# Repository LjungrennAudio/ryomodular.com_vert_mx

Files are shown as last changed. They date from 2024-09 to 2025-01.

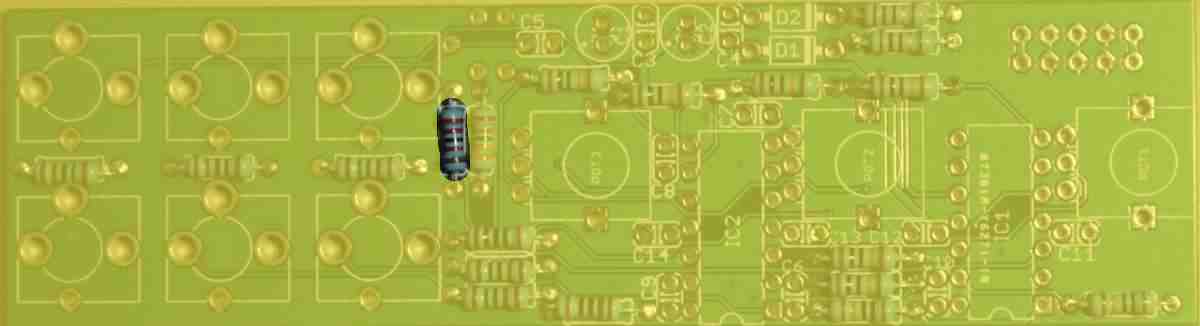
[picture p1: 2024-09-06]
docs/vert_mx/build pics/08 22k.jpg

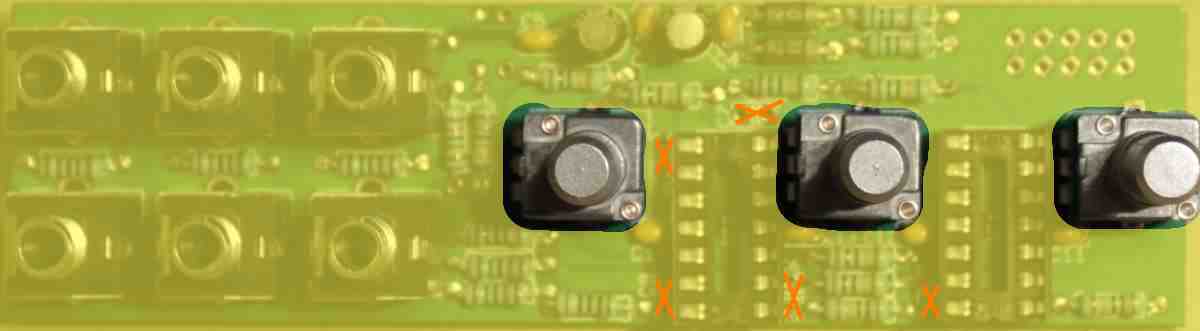
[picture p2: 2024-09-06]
docs/vert_mx/build pics/15 pots.jpg

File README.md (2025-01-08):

# ryomodular.com_vert_mx
 yet another new ryomodule - thi time the lon overdue vertmix mixer

2408302315

this is the repo for the ryodular.com vert_mx urorack format modular synth mixer module.

its been around as a prototypefor near 13 years and even visible on mod grid etc. yet never released so i guess it's about time really...

it's not much exciting am afraid - a 3 channel mixer with attenu version on each channel as well asbreakout signal option to allow just utility use without being used as a mixer.

it will  be available in ht new white panel/gold markings n pink knobs plus green leds along with the traditional ryo colourscheme too.
it should  be a pretty low price basic beginner DIY build friendly kinda module as oer ryo's traditional so far iutput so may not catch as much attention as the other new modules in the lineup but i feel c9mpelled to bring this cha[pter to closure at whatever cost the way things seem to be going. : D

if anyone cn come up with real exciting patch progaramming uses or unusuial thoughts for patch examples please tell me cos am not super inspired by thios one tbh - it's absolutely an essential you cnt do without in a system but it's not exactly the kimda thing you shout about - it just sits queitly in the corner doing it's job and eing an unsung hero of the modular ecosystem.

this will be cheap, unexciting and solid. it needs to e there as oart of the lineup but its not a weird quirky one or some kind of flagship - it just is.

202501080338 addendum

this is p much exactly the same story as the repos for the other modules of the set 'vert_mx, dp_switch, adda. brit_eq5', - i.e. it's not finished until it's finished and i aint attempting to bring order to chaos until it's all over so for now this aint gonna be sereing alotta change except for even more files being added. sorro.

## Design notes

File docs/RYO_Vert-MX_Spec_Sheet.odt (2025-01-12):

LjunggrenAudio RYOModular.com VERT_MX

A Three Channel Bipolar Attenuverting Mixer.

Dimensions

Height: 3U (128.5mm)

Width: 8HP (40.30mm)

Depth: ??mm (with power cable attached)

Weight: ???g (approx w/cable)

Current consumption

+12V rail 30mA

-12V rail 8mA

+5V rail no +5V supply required

Basic specifications

total frequency controllable range dc to 50kHz

max input/output audio signal 20Vpp

CV input range -10V to +10V

Max gain n/a

Nominal impedances

Audio signal input: ???ohm
Audio Signal output: ???ohm

CV input: ??kohm

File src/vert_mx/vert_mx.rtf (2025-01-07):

Vertmix

Download assembly manual here. (https://web.archive.org/web/20200128094051/http://ljunggrenaudio.com/vertmix.pdf)

Vertmix is out of production, new version coming but we don't know when.
It will have surface mounted resistors and ceramic capacitors in 0805 size. The rest of the components will be thru hole. Preliminary PCB illustration of version 1.5. (https://web.archive.org/web/20200128094051/http://ljunggrenaudio.com/products/VERTMIX/vertmixPCB1.5.gif)

* Regarding our PCB/panel only offerings, please note that these are mainly offered due to popular demand from the experienced DIY community. Hence we are counting on that you know what you are doing and how to source parts. If you feel the least bit uncertain, please consider going for the kit.

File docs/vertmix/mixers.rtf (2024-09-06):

Mixers

Ampmix

Download assembly manual here. (1MB) (https://web.archive.org/web/20200128094051/http://ljunggrenaudio.com/ampmix.pdf)
(https://web.archive.org/web/20200128094051/http://ljunggrenaudio.com/optodist.pdf)
An easy to build 4-channel amplifying mixer/attenuator with 2.0x gain (6dB) and 5.0V offset on each channel in an 8hp module. No calibration required.

Ampmix was designed as a handy CV mixer and processor with good precision, high input impedance and buffered outputs. It could be upgraded for even better precision as described in the assembly manual.

It will also work great with audio, even with full gain giving some distortion possibilities or gaining external gear.

It works as a 4 channel mixer,
1 attenuator + 3 channel mixer,
2 attenuators + 2 channel mixer
or 4 attenuators.
With up to 2.0x gain (6dB) on each channel.

If you chain channels you can get greater gain. You can chain any combination of channels it doesn't have to be in the described order.
Patch signal to IN1, OUT1 -> IN2 and OUT2 have 4x gain (12dB) total.
Continue with OUT2 -> IN3 and OUT3 have 8x gain (18dB) total.
Continue with OUT3 -> IN4 and OUT4 have 16x gain (24dB) total.

An offset voltage is generated then normaled to the inputs of the 4 channels, giving them a maximum of 5V out each with knobs turned full clockwise (2.0x gain). Please note that these offsets will affect the mixing if the channel hasn't been patched on its input or output, so turning all unused channels fully counter-clockwise/left (off) is advisable for a clean mix.

The Ampmix Kit is a novice-friendly project, it is a low part count, single-PCB build that only requires the most basic experience in PCB soldering and module assembly. Kits comes supplied with PCB, front panel (PCB material), component kit, knobs, power cable and mounting screws. Solder and tools are not supplied.

Download assembly manual here. (1MB) (https://web.archive.org/web/20200128094051/http://ljunggrenaudio.com/ampmix.pdf)
Download schematics here. (https://web.archive.org/web/20200128094051/http://ljunggrenaudio.com/products/AMPMIX/ampmix%20schematics%201.3.gif)

Basic specifications
Width: 8hp
Depth with power cable attached: Less than 35 mm.
Power: +/- 22 mA

Vertmix

Download assembly manual here. (https://web.archive.org/web/20200128094051/http://ljunggrenaudio.com/vertmix.pdf)

Vertmix is out of production, new version coming but we don't know when.
It will have surface mounted resistors and ceramic capacitors in 0805 size. The rest of the components will be thru hole. Preliminary PCB illustration of version 1.5. (https://web.archive.org/web/20200128094051/http://ljunggrenaudio.com/products/VERTMIX/vertmixPCB1.5.gif)

* Regarding our PCB/panel only offerings, please note that these are mainly offered due to popular demand from the experienced DIY community. Hence we are counting on that you know what you are doing and how to source parts. If you feel the least bit uncertain, please consider going for the kit.

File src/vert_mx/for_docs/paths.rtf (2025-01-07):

Switches

PATHS - A Cycling Sequential Switch

A 4:4 cycling sequential switch, featuring simultaneous forward/reverse stepping, hold, reset, and an additional voltage controlled mode based on the same design as our VC Sequencer. Also on board are push buttons for each function enabling you to play and perform the switching with a more human input.

This sequential switch will do all your standard 1>2, 1>3, 1>4 or the other way around with great real-time as well as external voltage controllability.

But its when you start playing around with multiple sources and destinations that things start getting fun and weird! You could for instance shuffle around four different trigger patterns to trigger four different percussive generators for interesting variations, or why not 4 oscillators shuffling between 4 different destinations, panned and processed in various ways?

Whatever your sequential switch application might be, we're confident the Paths is up to the task!

Just like the VC Sequencer it is clockable by very high clock rates (100 kHz tested) and CVable with full audio range. All for your experimental waveshaping duties.

Clock Mode
When clocking with FWD clock input or button the sequence will advance one step forward. When clocking with REV clock input or button the sequence will advance one step in reverse.

If a clock comes in exactly at the same time on both inputs the forward will have priority over the reverse.

CV Mode
In CV mode there is two CV inputs. The one that shares the reverse clock input is full wave rectified and the one that shares the forward clock input is half wave rectified. It uses an active rectifier without voltage drop or a dead zone around 0V.

The half wave rectified (FWD) with one bump on the rectifier symbol, will clip any signal below 0V and above 5V. The difference to the full wave rectified input (REV) with two bumps on the rectifier symbol, is that it will turn any negative volt into positive as well. So -1V is the same as +1V and -5V is the same as +5V etc.

The CV inputs are mixed together so they can be used at the same time.

The steps toggle switch and the red buttons are inactive in CV mode.
To limit the number of steps in CV mode you can use an attenuator to attenuate the CV down to only reach 2 or 3 steps.

Four separate switches
It's essentially four separate switches that is commonly controlled and shares ins and outs.
When I/O1 is connected to O/I1, I/O2 is connected to O/I2 and so on.
When I/O1 is connected to O/I2, I/O2 is connected to O/I3 and so on, and I/O4 is connected to O/I1.
When I/O1 is connected to O/I3, I/O2 is connected to O/I4 and I/O3 is connected to O/I1 and so on.
All the routings can be seen in the picture linked here, each module represent one of the four steps as the LEDs next to the jacks indicate. (https://web.archive.org/web/20200129120501/http://ljunggrenaudio.com/products/PATHS/pathsrouting.png)

2/4/3 Steps and reverse direction.
The toggle switch that controls number of steps works a little pequliar due to the CMOS CD4516 counter IC. Reset always takes it back to step 1/first LED lit. We could then choose to always let it reset on step 3 and 4 respectively for 2 and 3 steps.

But when run in reverse it would mean that with the toggle switch on 2 steps it would go 2 steps before it hits step 3 and resets. All good so far but when 3 steps were selected it would just stay on step 1 when clocked in reverse as step 4 would be next and that would reset it. So we choose to let it reset on step 2 when you run it in reverse so it goes 1 -> 4 -> 3 -> 1.

This opens up the possibility to clock forward and reverse with different triggers or button presses and therefore make it go in controlled irregular patterns. 1 -> FWD -> 2 -> FWD -> 3 -> REV -> 1 -> REV -> 4 -> REV -> 3-> FWD -> 1 as an example. Add a little random trigs or button presses and it will be less controlled.

Two parallel 1:2 switches
You could also patch it like two commonly controlled parallel 1:2 switches if you only run it in one direction. Easiest is forward direction: I/O1 : O/I1 & O/I2 respectively I/O3 : O/I3 & O/I4

Kits and price
Kits comes supplied with PCBs, front panel (PCB material), component kit, power cable and mounting screws. Solder and tools are not supplied.

Download assembly instructions and BOM here (2.7MB). (https://web.archive.org/web/20200129120501/http://ljunggrenaudio.com/paths.pdf)
Download schematics here. (https://web.archive.org/web/20200129120501/http://ljunggrenaudio.com/products/PATHS/PATHS%201.1%20schematic.gif)

Basic specifications
Width: 8 hp
Depth: 46 mm.
Power: +12V 30 mA / -12V 8 mA

* Regarding our PCB/panel only offerings, please note that these are mainly offered due to popular demand from the experienced DIY community. Hence we are counting on that you know what you are doing and how to source parts. If you feel the least bit uncertain, please consider going for the kit.

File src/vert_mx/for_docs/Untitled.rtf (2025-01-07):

Anatomy of a module page

QuickStart

What’s in manual - each section as a bullet

Links to dls

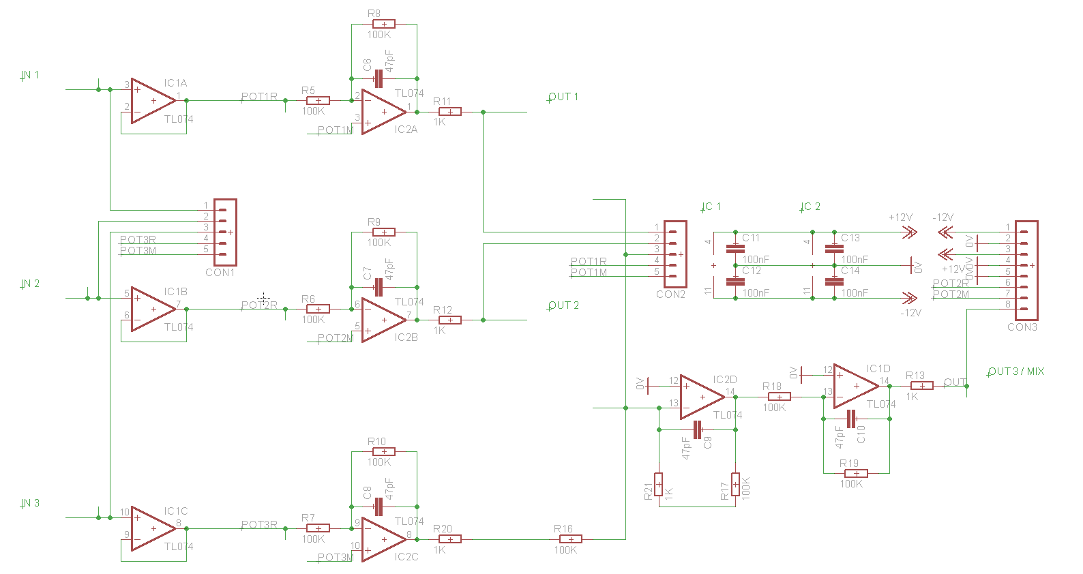
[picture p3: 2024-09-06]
docs/vertmix/downloads/vertmix pcb 2 schematic.png

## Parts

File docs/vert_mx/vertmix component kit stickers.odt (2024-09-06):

R16, R17 Resistor 2 pcs Value: 2K Vertmix 1.0 www.ljunggrenaudio.com | | R5, R6, R7, R8, R9, R10, R18, R19 Resistor 8 pcs Value: 100K Vertmix 1.0 www.ljunggrenaudio.com | | R11, R12, R13, R14, R15 Resistor 5 pcs Value: 1K Vertmix 1.0 www.ljunggrenaudio.com
R1, R2 Resistor 2 pcs Value: 10R Vertmix 1.0 www.ljunggrenaudio.com | | R4 Resistor 1 pcs Value: 22K Vertmix 1.0 www.ljunggrenaudio.com | | R3 Resistor 1 pcs Value: 33K Vertmix 1.0 www.ljunggrenaudio.com
TRIM1 Trimmer 1 pcs Value: 20K Vertmix 1.0 www.ljunggrenaudio.com | | C1, C2 Electrolytic 2 pcs Value: 10µF Vertmix 1.0 www.ljunggrenaudio.com | | C3, C4, C5, C11, C12, C13, C14 Capacitor 7 pcs Value: 100nF X7R ceramic Vertmix 1.0 www.ljunggrenaudio.com
POWER CABLE | | J1, J2, J3, J4, J5, J6 3.5mm jack 6 pcs PJ301BM washer 6 pcs nut 6 pcs Vertmix 1.0 www.ljunggrenaudio.com | | POT1, POT2, POT3 Rotary potentiometer 3 pcs Value: 100K Linear taper Vertmix 1.0 www.ljunggrenaudio.com
POWER Power header 1 pcs 10 pin boxed keyed header Vertmix 1.0 www.ljunggrenaudio.com | | Knobs Small fluted skirtless, cream 3 pcs Vertmix 1.0 www.ljunggrenaudio.com | | Mounting screws M3x6, Pozi, Black 2 pcs Vertmix 1.0 www.ljunggrenaudio.com
PCB 1 pcs Vertmix 1.0 www.ljunggrenaudio.com | | Faceplate 6hp 2mm, PCB (FR4) material 1 pcs black Vertmix 1.0 www.ljunggrenaudio.com | | Roll Your Own KIT Vertmix 1.0 Assembly manual as PDF can be found here: http://ljunggrenaudio.com/vertmix.pdf www.ljunggrenaudio.com

IC1, IC2 14 pin DIP socket 2 pcs TL084 2 pcs Vertmix 1.0 www.ljunggrenaudio.com | | IC1, IC2 14 pin DIP socket 2 pcs TL074 2 pcs Vertmix 1.0 www.ljunggrenaudio.com | | ← ONE
D1, D2 Diode 2 pcs SB130 Schottky Vertmix 1.0 www.ljunggrenaudio.com
| | | | Roll Your Own KIT Vertmix 1.0 Assembly manual as PDF can be found here: http://ljunggrenaudio.com/vertmix.pdf www.ljunggrenaudio.com

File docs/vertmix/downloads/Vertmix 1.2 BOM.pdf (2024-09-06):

### Sheet1

Qty | Value | Device | Parts
1 | | 10 pin boxed header | POWER
1 | | 3 pins single row strip (jumper) | JP1
6 100nF | | Ceramic cap X7R | C3, C4, C11, C12, C13, C14
1 10K | | Resistor 3.5mm | R3
2 10R | | Resistor 7mm | R1, R2
4 10uF | | Electrolytic | C1, C2, C5, C9
3 22K linear | | Potentiometer | POT1, POT2, POT3
15 22K | | Resistor 3.5mm 1% | R5, R6, R7, R8, R9, R10, R14, R15, R16, R17, R18, R19, R20, R21, R22
3 330R | | Resistor 3.5mm | R4, R11, R12
3 68pF | | Ceramic cap | C6, C7, C8
6 ERTHENVAR_JACK | | 3.5mm minitele jack | IN1, IN2, IN3, OUT1, OUT2, OUT3
1 LM4040 5V | | Voltage reference shunt | D3
2 SB130 | | Schottky rectifier diode | D1, D2
2 TL084 | | Opamp | IC1, IC2

Vertmix 1.2 BOM

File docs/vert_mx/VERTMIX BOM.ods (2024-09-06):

Ljunggren Audio – Roll Your Own
Bill of material
VERTMIX
1.0
TYPE | PART | VALUE | PCS | NOTE
Resistor | R5,R6,R7,R8,R9,R10, R18,R19 | 100K | 8 | 1,00%
Resistor | R11,R12,R13,R14,R15 | 1K | 5 | 1,00%
Resistor | R16,R17 | 2K | 2 | 1,00%
Resistor | R1,R2 | 10R | 2
Resistor | R3 | 33K | 1
Resistor | R4 | 22K | 1
Diode | D1,D2 | SB130 | 2 | Schottky power polarity protection
Capacitor | C3,C4,C5,C11,C12,C13,C14 | 100nF | 7 | Ceramic X7R 2.5mm pin pitch
IC Socket | IC1,IC2 | 14 pin | 2
OpAmp | IC1,IC2 | TL074 | 2 | or TL084
Electrolytic | C1,C2 | 10µF | 2 | 2mm pin pitch, 5mm dia, 5mm height
Trimmer | TRIM1 | 20K | 1 | Offset voltage calibration
Power header | POWER | 10 pin | 1 | boxed
Jack | J1,J2,J3,J4,J5,J6 | 3.5mm | 6 | PJ301BM
Rotary Pot. | POT1,POT2,POT3 | 100K lin | 3
Knobs | Small fluted skirtless | cream | 3
Screws | Black, Pozi | M3x6 | 2 | Mounting screws
PCB |  |  | 1
Faceplate | PCB material (FR4) | black | 1
Power cable | Eurorack power cable |  | 1 | 10pin ↔ 16pin

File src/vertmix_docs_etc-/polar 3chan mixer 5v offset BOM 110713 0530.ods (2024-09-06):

Added to Eagle | Schem Code | Type | Value | Unit | Quantity | Name | ELFA # | Mouser # | Electrokit # | Case | Comment
 | C6,C7,C8,C10 | Capacitor | 47 | pF | 4 | C0G 2.5mm
 | C9 | Capacitor | 22 | pF | 1 | C0G 2.5mm
 | C3,C4,C5,C11,C12,C13,C14 | Capacitor | 100 | nF | 7 | X7R 2.5mm
 | C1,C2 | Electrolytic | 10 | uF | 2 | 5mm dia. 2mm pin pitch |  |  |  |  | Panasonic small elec.
 | D1,D2 | Schottky |  |  | 2 | SB130
 | IC1,IC2 | Op Amp |  |  | 2 | TL074 |  |  |  |  | use DIP-14 sockets
 | R3 | Resistor | 22 | k | 1
 | R4 | Resistor | 10 | k | 1
 | R14,R15,R16,R17 | Resistor | 220 | k | 4 | 1,00%
 | R5,R6,R7,R8,R9,R10,R18,R19 | Resistor | 100 | k | 8 | 1,00%
 | R11,R12,R13 | Resistor | 1 | k | 3 | 1,00%
 | R1,R2 | Resistor | 10 | r | 2
 | POT1,POT2,POT3 | Lin Pot | 100 | k | 3
 | TRIM1 | trimpot | 25 | k | 1 |  |  |  |  |  | 5V reference calibration.
 | J1,J2,J3,J4,J5,J6 | jack | 3,5 | mm | 6 | Erthenvar style
 | Power Connector |  |  |  | 1 | 2x5 pin

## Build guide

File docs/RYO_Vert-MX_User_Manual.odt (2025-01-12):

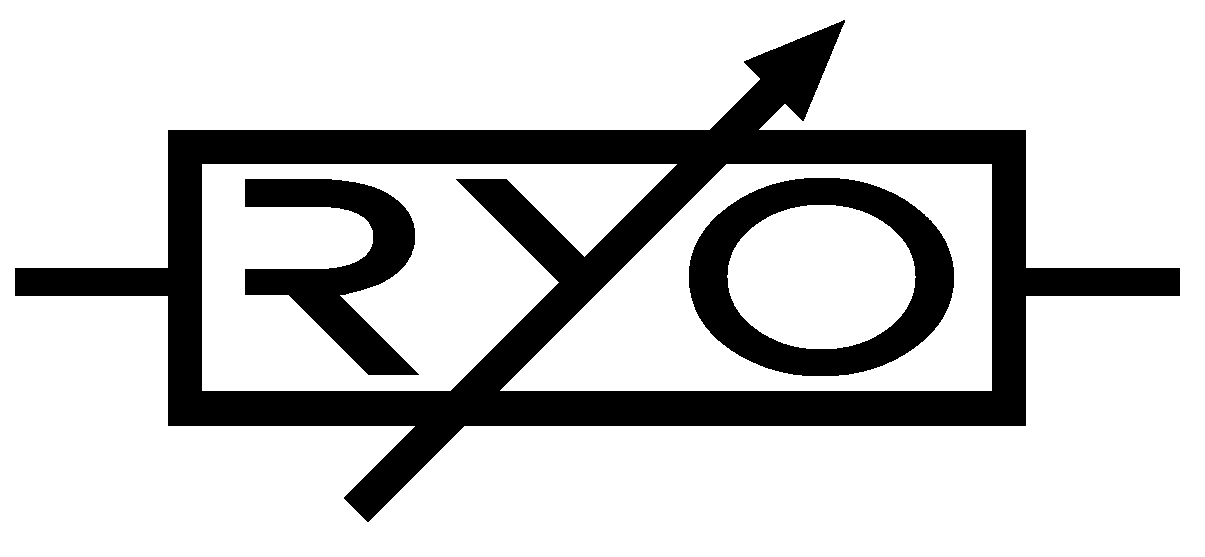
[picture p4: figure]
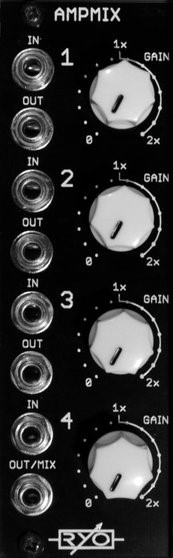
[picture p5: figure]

LjunggrenAudio RYO Ampmix

A 4-channel amplifying mixer in 8hp

Quickstart – what is the Vert_MX and how do I get going?

An easy to build 3-channel attenuverting mixer with -1.0 to 1.0x gain (0dB) and optional 5.0V offset on each channel in an 8hp module. No calibration required.

Vert_MX was designed as a handy CV mixer and processor with good precision, high input impedance and buffered outputs. It could be upgraded for even better precision as described in the assembly manual. It will also work great with audio.

Basic specifications

Width: 8hp

Depth with power cable attached: Less than 35 mm.

Power: +/- 22 mA

Installation

To begin installation, please make sure that:

- you have a standard pinout eurorack bus board

- you have +12V and -12V power rails on that bus board [no +5V supply is required]

- the power rails are not overloaded

!!!Before installing this module disconnect the power from your system!!!

- Double check the polarity of the ribbon cable - The red stripe should be aligned with the -12V rail, on both the module and on the bus board

[we use shrouded headers but it's still possible a cable has been assembled with the stripe on the wrong side of the shroud so always double check!].

Also make sure when using busboards without shrouded headers that the pins aren't transposed a row vertically or horizontally – all pins should insert into holes on the cable.

Although we use both fuses and schottky diodes to provide reverse polarity and excess current protection, we do not take any responsibility for damages caused by wrong power supply connection!

After you have connected everything, double checked it and ensured your case is closed such that no power lines can be touched by your hand or any stray cables drop into holes, turn on your system and test the module

The Ampmix Kit is a novice-friendly project, it is a low part-count, single-PCB build that only requires the most basic experience in PCB soldering and module assembly. blank blank blank blank blank.

It works as a 3 channel mixer,

1 attenuvertor + 2 channel mixer,

or 3 attenuvertors.

With up to 5V offset (+/-) on each channel.

If you chain channels you can get greater offset up to max rail voltage of +/-12V. You can chain any combination of channels it doesn't have to be in the described order.

Patch signal to IN1, OUT1 -> IN2 and OUT2 have 10V offset (10V) max.

Continue with OUT2 -> IN3 and OUT3 have 12V offset (12V) max.

An offset voltage is generated then normaled to the inputs of the 3 channels, giving them a maximum of +5V out each with knobs turned full clockwise (+1.0x gain). Please note that these offsets will affect the mixing if the channel hasn't been patched on its input or output, so turning all unused channels to center (off) is advisable for a clean mix.

The module can be used as a basic attenuator; by patching a signal to any channel and taking it's individual output as the out, whilst keeping gain between fully CCW and center as desired.

lank blank blank blank blank blank.

Dimensions

Height: 3U (128.5mm)

Width: 8HP (40.30mm)

Depth: 35mm (with power cable attached)

Weight: ???g

Current consumption

+12V rail 22mA

-12V rail 22mA

+5V rail no +5V supply required

Basic specifications

total frequency controllable range dc to 50kHz

max input/output audio signal 20Vpp

CV input range 0V to +10V

Max gain 0dB (1.0x) gain per channel

Nominal impedances

Audio signal input: 22k ohm
Audio Signal output: in loop compensated

CV input: n/a

Patch ideas:

Although uses of mixers in patch examples and ideas are found readily online and in some books, and similarly those familiar with using attenuators will be familiar with the basics, there are other less obvious ways to use the ampmix in patches in your modular rig:

below i've include some inspiring words to encourage other patches that might be tried; and, as ever, experiment – RYO modules are designed with all necessary protection and fail-safes so you can just start plugging in patch cables and see what happens!

Overdrive other modules;

many modules can be fed a hot signal to overdrive the input stage giving a nice distortion or warm tonality – this is especially true for VCAs, filters and some mixers.

Boost/attenuate less commonly varied signal;

not only commonplace signals like the main audio in an output chain or the end output of a patch might need boosting if gain is low, also try boosting as well as attenuating FM modulators, AM modulators and other secondary waveforms in a patch so that the resulting sound output from a carrier VCO/VCF/VCA is different.

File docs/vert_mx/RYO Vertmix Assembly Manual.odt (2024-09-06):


Ljunggren Audio

Roll Your Own

Vertmix

Version: Bipolar mixer/att 1.0

Bill Of Material

Assembly instructions

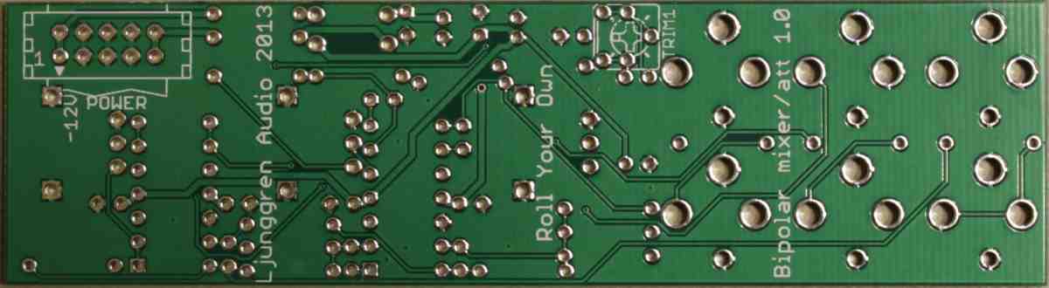
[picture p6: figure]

Empty PCB bottom.

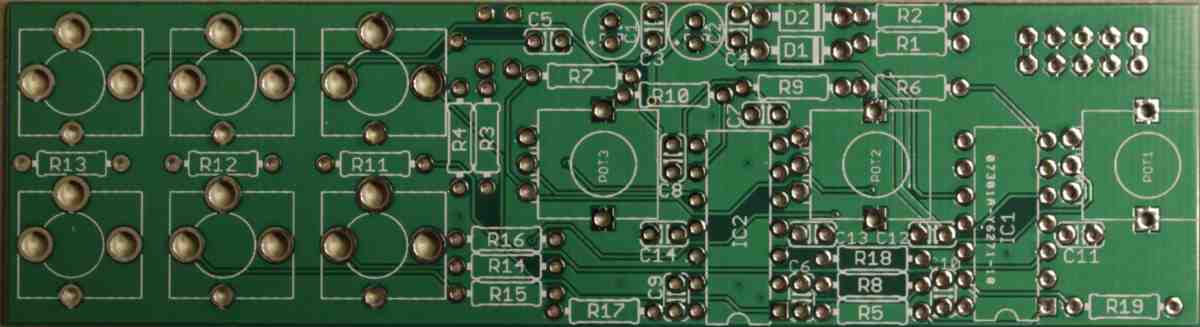
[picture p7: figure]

Empty PCB top.

Step 1

Solder resistors. Resistors are not sensitive to mounting direction.

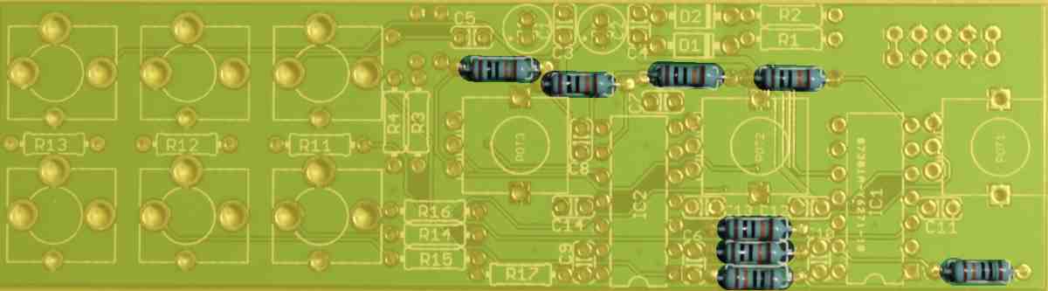
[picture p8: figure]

R5, R6, R7, R8, R9, R10, R18, R19 100K

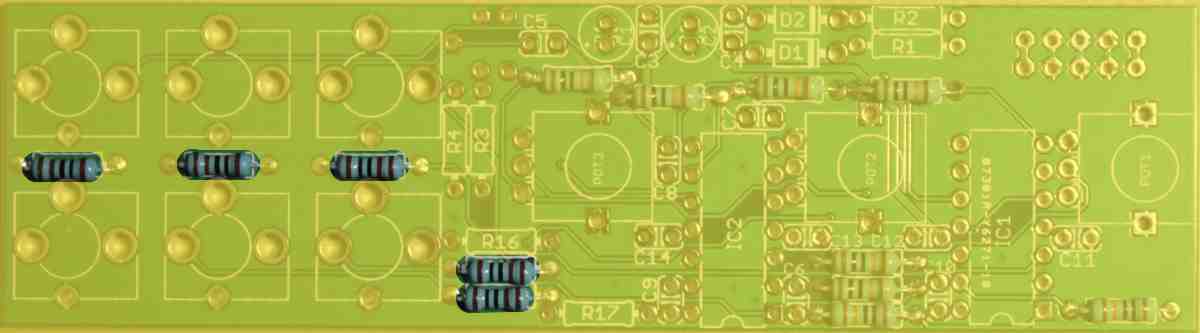
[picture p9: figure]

R11, R12, R13, R14, R15 1K

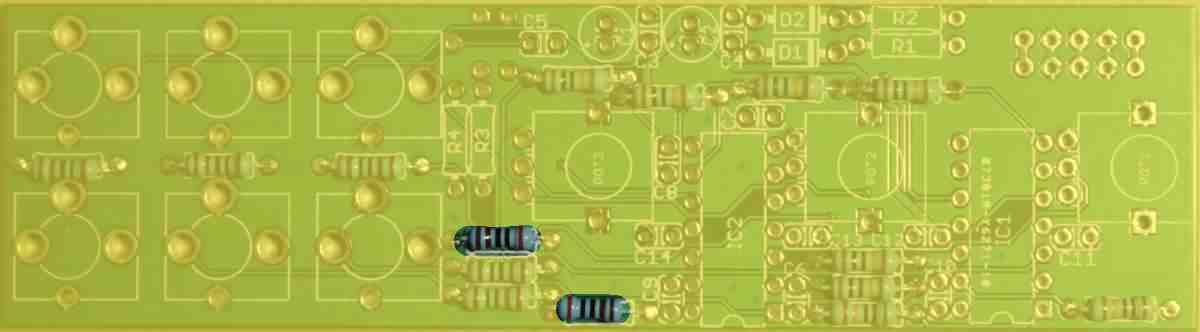
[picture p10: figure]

R16, R17 2K

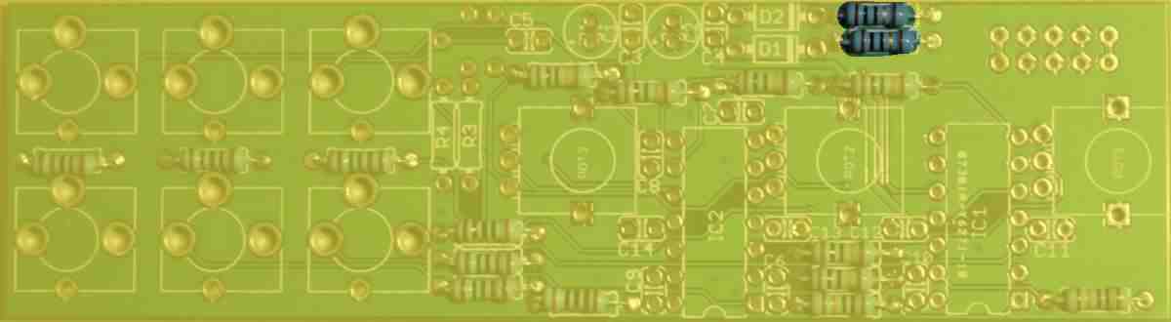
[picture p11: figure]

R1, R2 10R

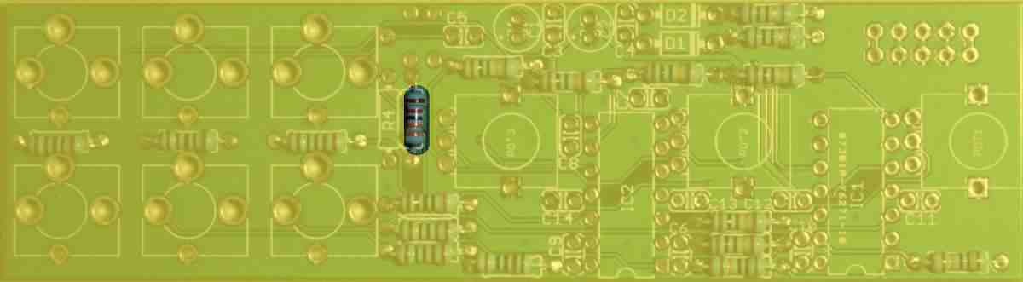
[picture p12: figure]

R3 33K


R4 22K

Step 2

Solder reverse polarity protection diodes. The stripe on the diodes must be on the same side as indicated in the silk screen.

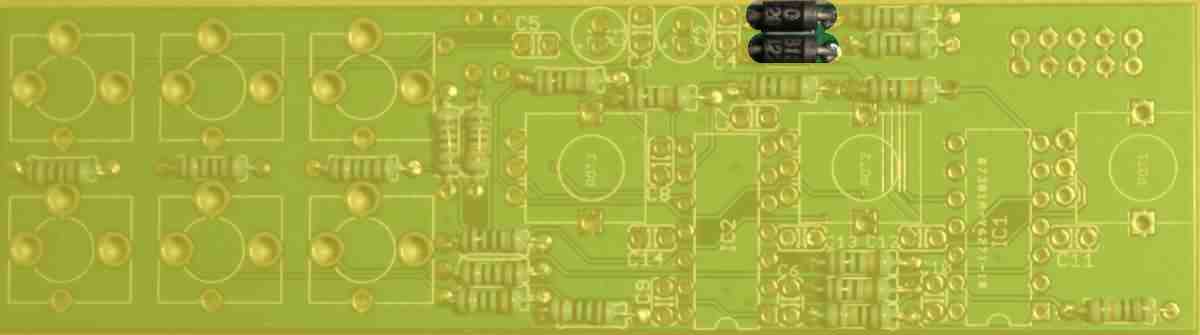
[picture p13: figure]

D1, D2 SB130

Step 3

Solder ceramic capacitors. Ceramic capacitors are not sensitive to mounting direction.

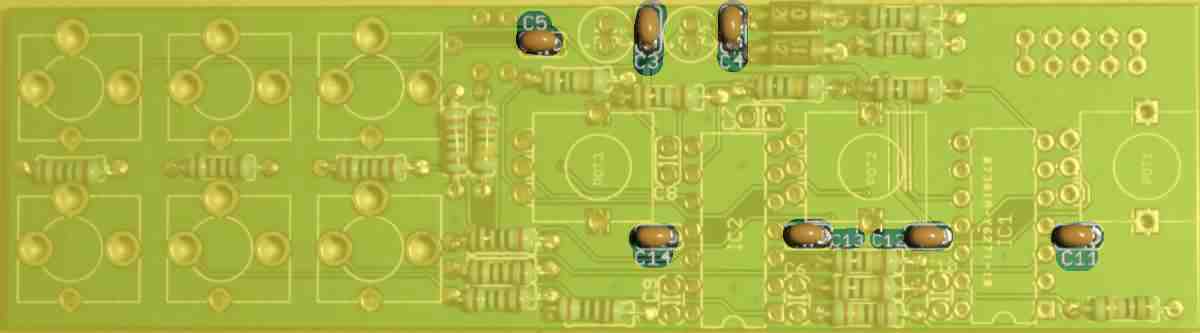
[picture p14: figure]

C3, C4, C5, C11, C12, C13, C14 100nF

Step 4

Solder sockets. Match the IC sockets indent (pin 1) with the silk screens. Don't mount the crossed over ceramic capacitors as they are unnecessary.

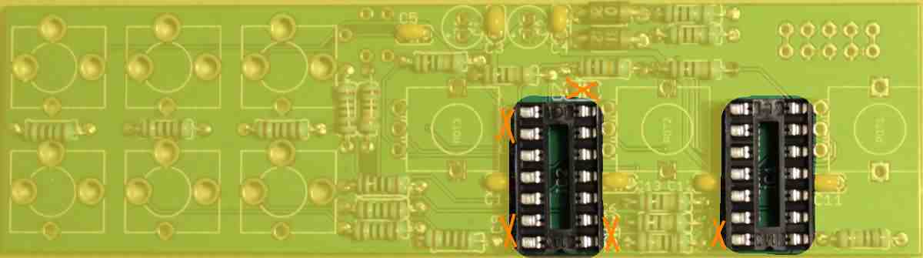
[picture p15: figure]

IC1, IC2 sockets. IC's will be mounted later.

Step 5

Solder Electrolytics. Long leg is + (anode).

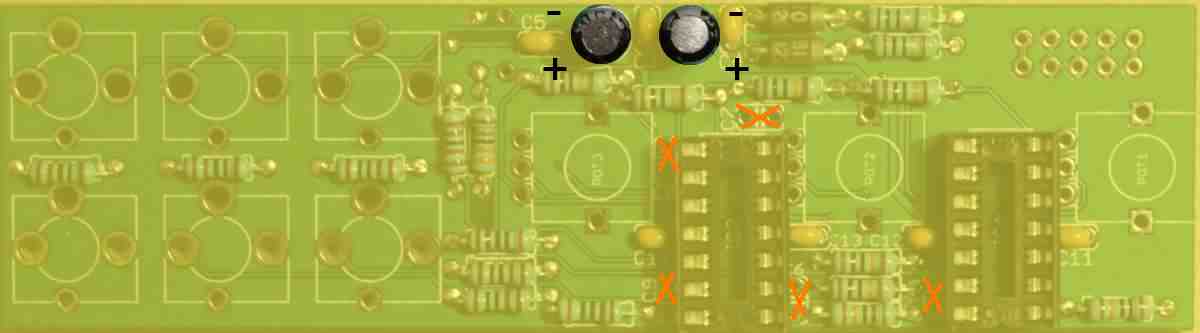
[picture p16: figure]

C1 10µF, C2 10µF

Step 6

Solder trimmer. Only 3 of the 5 holes are used, the extra 2 holes are for fitting trimmers with different appearence.

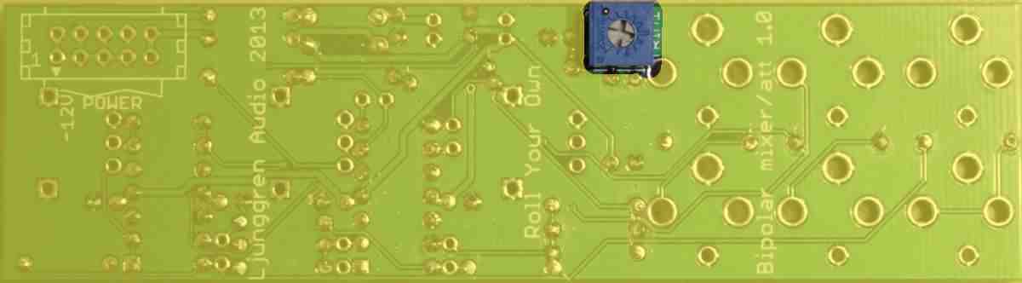
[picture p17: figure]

TRIM1 20K

Step 7

Solder the jacks.

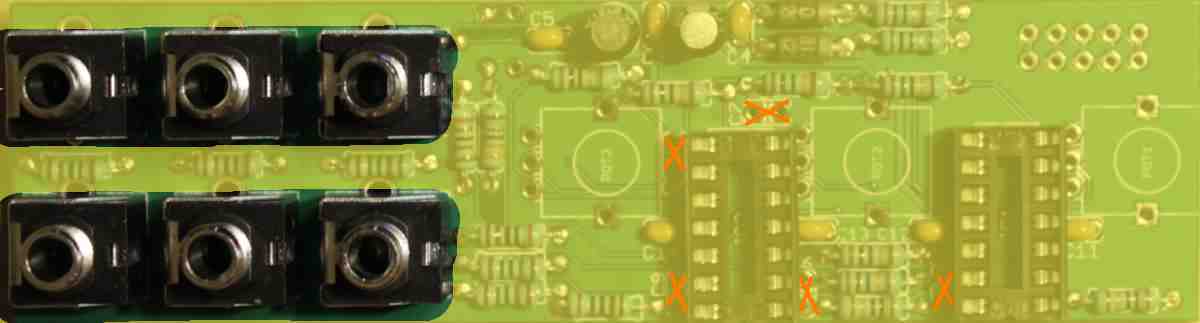
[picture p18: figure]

J1, J2, J3, J4, J5, J6 PJ301BM

Step 8

Remove the nuts and washers from the potentiometers. Cut off the small metal tab sticking out indicated by a circle below. Use a cheap plier/nipper for this step, save your expensive ones for other tasks.

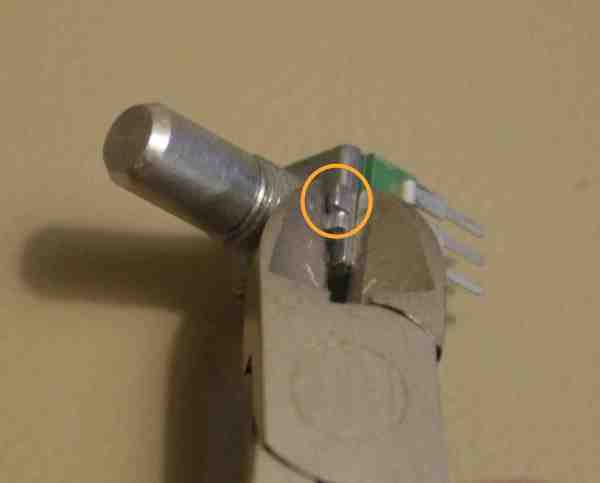
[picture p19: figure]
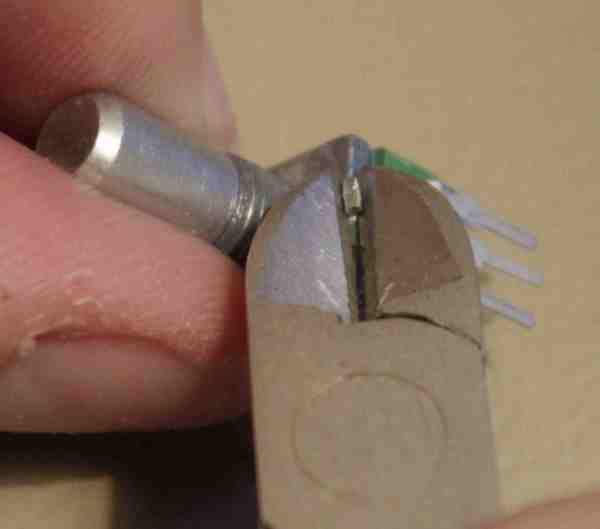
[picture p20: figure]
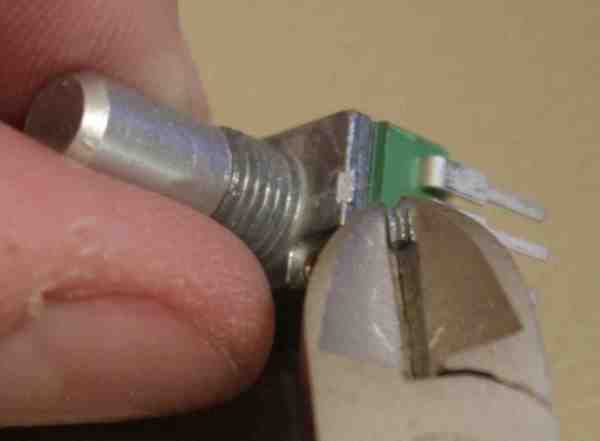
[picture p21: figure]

And solder them in place.


POT1, POT2, POT3 100K linear

Step 9

Solder the keyed boxed power header. Pay extra attention to the direction. The triangle (pin 1) must be at the -12V side. In the picture below you can see the direction of the keyed opening in the boxed header.

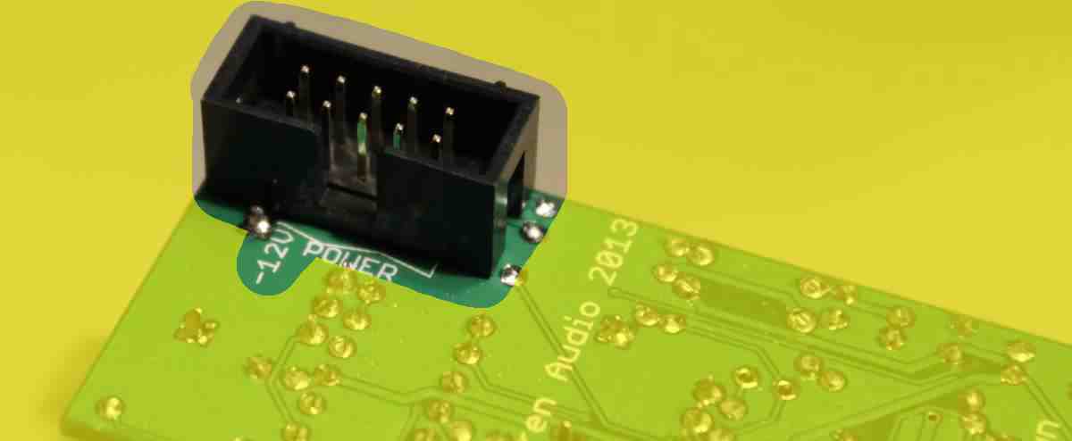
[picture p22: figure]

POWER

Step 10

Mount the IC's. The IC's indent or dot marking pin 1 must match the silk screen direction.

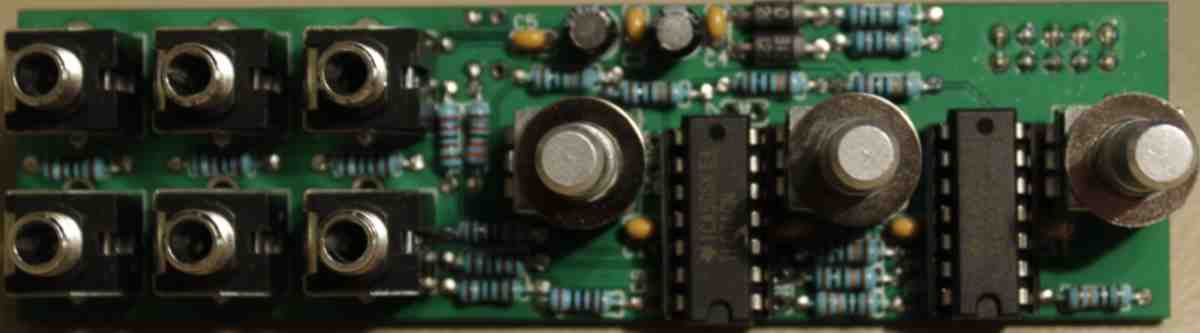
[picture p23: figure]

Step 11

Mount the panel. Use 8 mm wrench socket for the jacks and switch and 10 mm for the potentiometers.

Potentiometers: Use the washers that was originally attached to the potentiometers under the panel and the nut over the panel.

Jacks: No washers under the panel. One washer and one nut per jack over the panel.

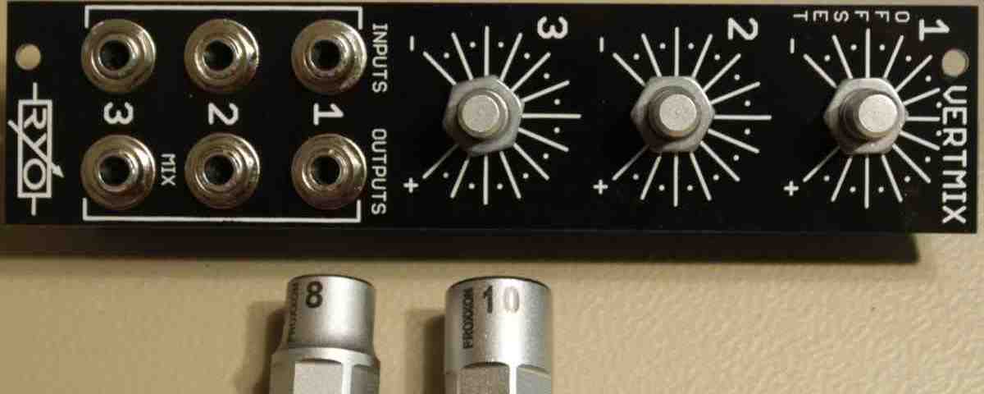
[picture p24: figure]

Step 12

Mount the knobs on the potentiometers.

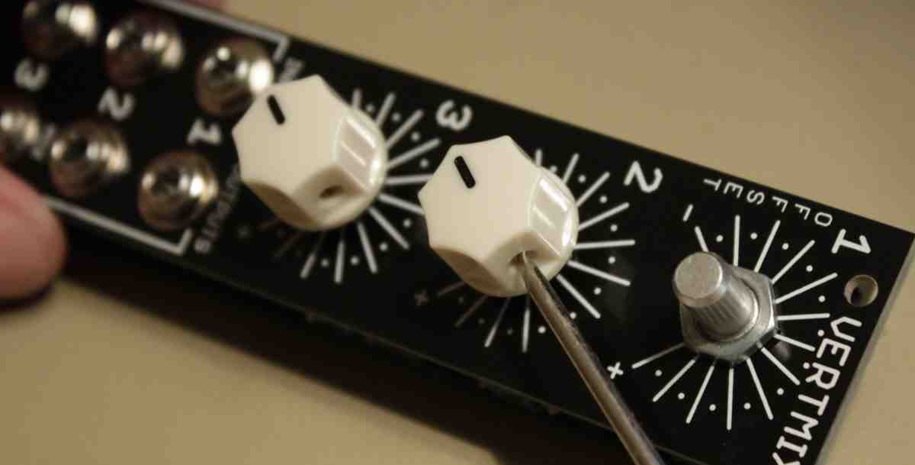
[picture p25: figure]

Step 13

Mount the power cable. Red stripe at -12V.

Finished module!

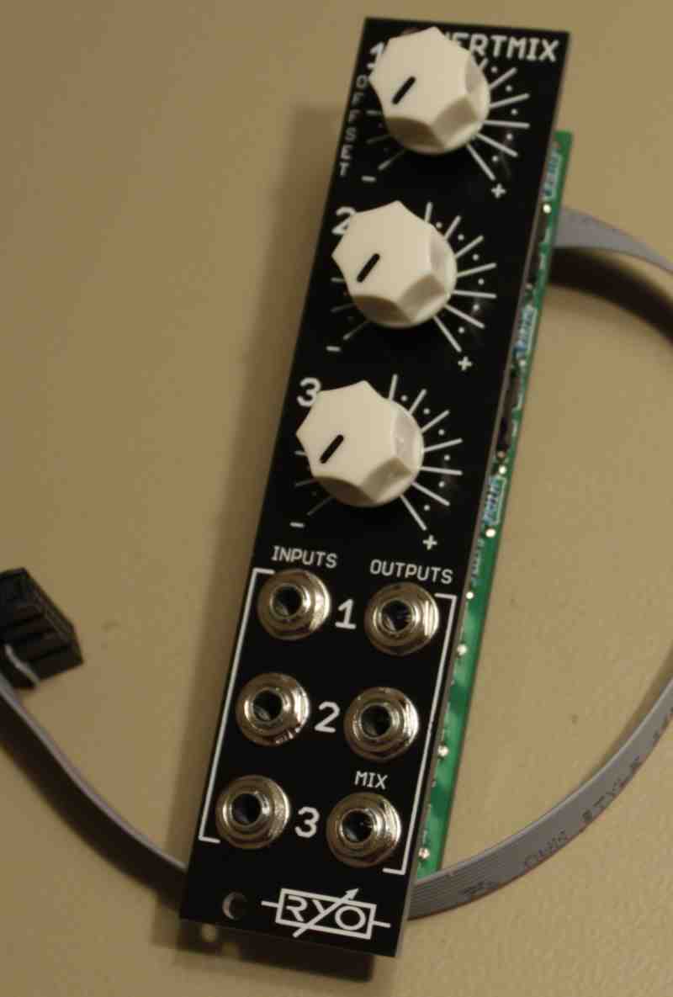
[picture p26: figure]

Calibration

1.

Turn channel 1 knob fully CW (right).

2.

Connect a patch cable to channel 1 output. Leave channel 1 input jack unconnected.

3.

Measure voltage with a multimeter between the tip and ring (signal and ground) of the patch cable.

4.

Adjust trimmer until you measure 5V on the multimeter.

There will be some small variations between channel 1 out and mix out as well as between fully negative and fully positive setting, due to the use of 1% resistors and standard opamps with up to 6mV offset. If you use 0.1% resistors where the BOM say 1% and opamps with lower offset you will get better precision for offset, attenuating and mixing.

Although Vertmix have 1k isolation resistors on the outputs so if you patch them to inputs without resistorless buffers there will be a voltage droop and it will increase with passive multing.

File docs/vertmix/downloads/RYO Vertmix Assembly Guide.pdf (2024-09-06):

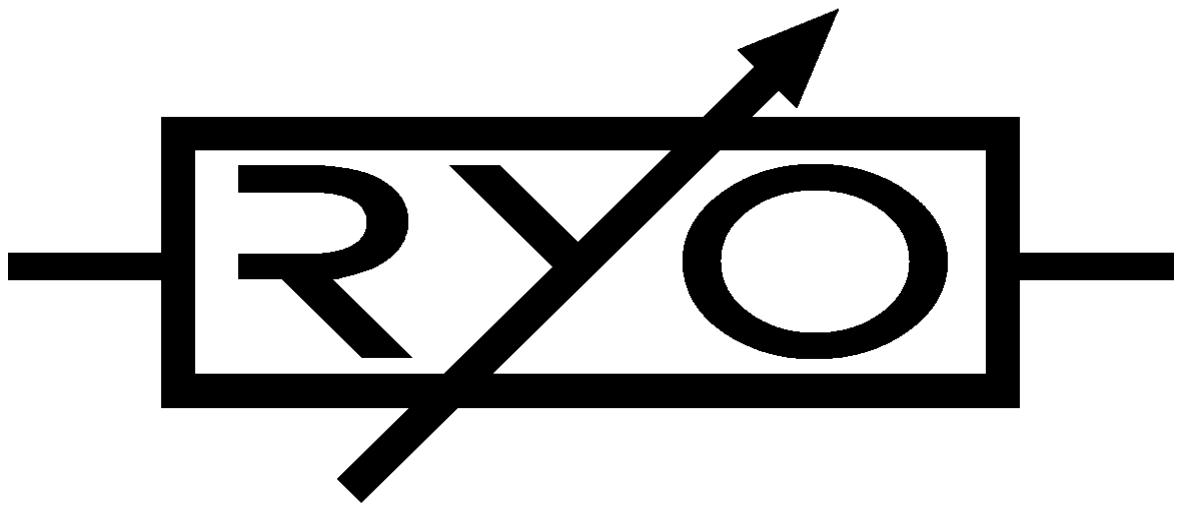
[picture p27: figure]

# Ljunggren Audio Roll Your Own Vertmix

Version: Bipolar mixer/att 1.0

## Bill Of Material

TYPE | PART | VALUE | PCS NOTE
Resistor | R5,R6,R7,R8,R9,R10, R18,R19 | 100K | 8 | 1,00%
Resistor | R11,R12,R13,R14,R15 | 1K | 5 | 1,00%
Resistor | R16,R17 | 2K | 2 | 1,00%
Resistor | R1,R2 | 10R | 2
Resistor | R3 | 33K | 1
Resistor | R4 | 22K | 1
Diode | D1,D2 | SB130 | 2 | Schottky power polarity protection
Capacitor | C3,C4,C5,C11,C12,C13,C14 | 100nF | 7 | Ceramic X7R 2.5mm pin pitch
IC Socket | IC1,IC2 | 14 pin | 2
OpAmp | IC1,IC2 | TL074 | 2 | or TL084
Electrolytic | C1,C2 | 10µF | 2 | 2mm pin pitch, 5mm dia, 5mm height
Trimmer | TRIM1 | 20K | 1 | Offset voltage calibration
Power header | POWER | 10 pin | 1 | boxed
Jack | J1,J2,J3,J4,J5,J6 | 3.5mm | 6 | PJ301BM
Rotary Pot. | POT1,POT2,POT3 | 100K lin | 3
Knobs | Small fluted skirtless | cream | 3
Screws | Black, Pozi | M3x6 | 2 | Mounting screws
PCB | | | 1
Faceplate | PCB material (FR4) | black | 1
Power cable | Eurorack power cable | | 1 | 10pin ↔ 16pin

## Assembly instructions

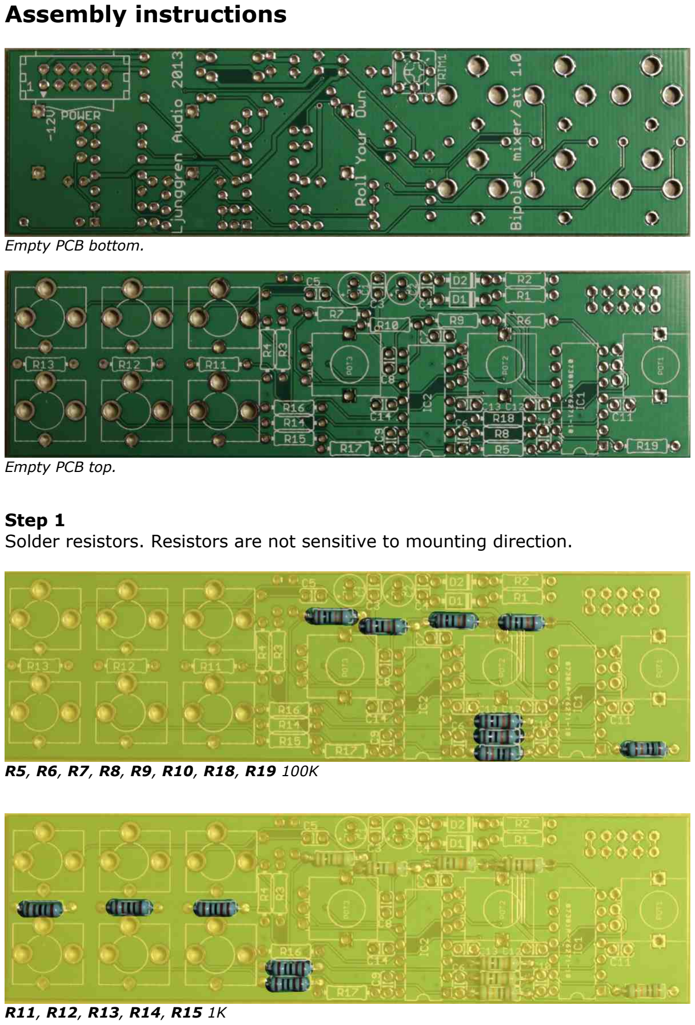
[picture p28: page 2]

Empty PCB bottom.

Empty PCB top.

Step 1
Solder resistors. Resistors are not sensitive to mounting direction.

R5, R6, R7, R8, R9, R10, R18, R19 100K

R11, R12, R13, R14, R15 1K

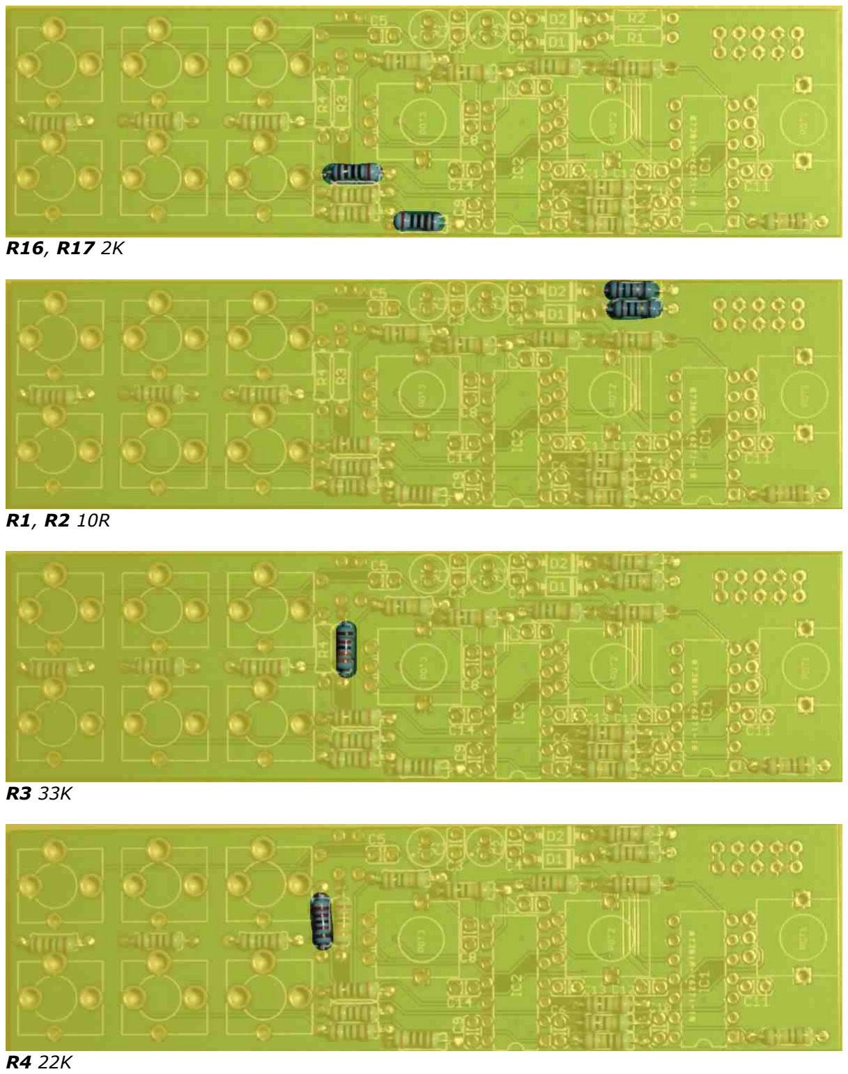
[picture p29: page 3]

R16, R17 2K

R1, R2 10R

R3 33K

R4 22K

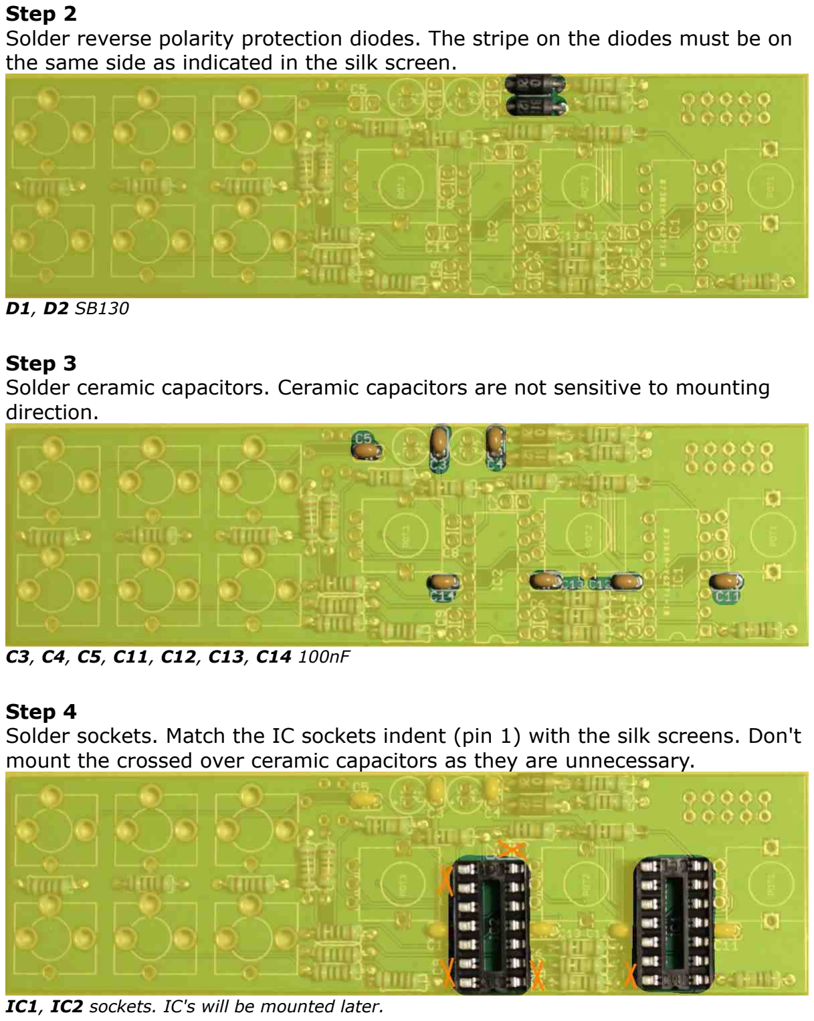
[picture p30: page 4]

Step 2
Solder reverse polarity protection diodes. The stripe on the diodes must be on the same side as indicated in the silk screen.

D1, D2 SB130

Step 3
Solder ceramic capacitors. Ceramic capacitors are not sensitive to mounting direction.

C3, C4, C5, C11, C12, C13, C14 100nF

Step 4
Solder sockets. Match the IC sockets indent (pin 1) with the silk screens. Don't mount the crossed over ceramic capacitors as they are unnecessary.

IC1, IC2 sockets. IC's will be mounted later.

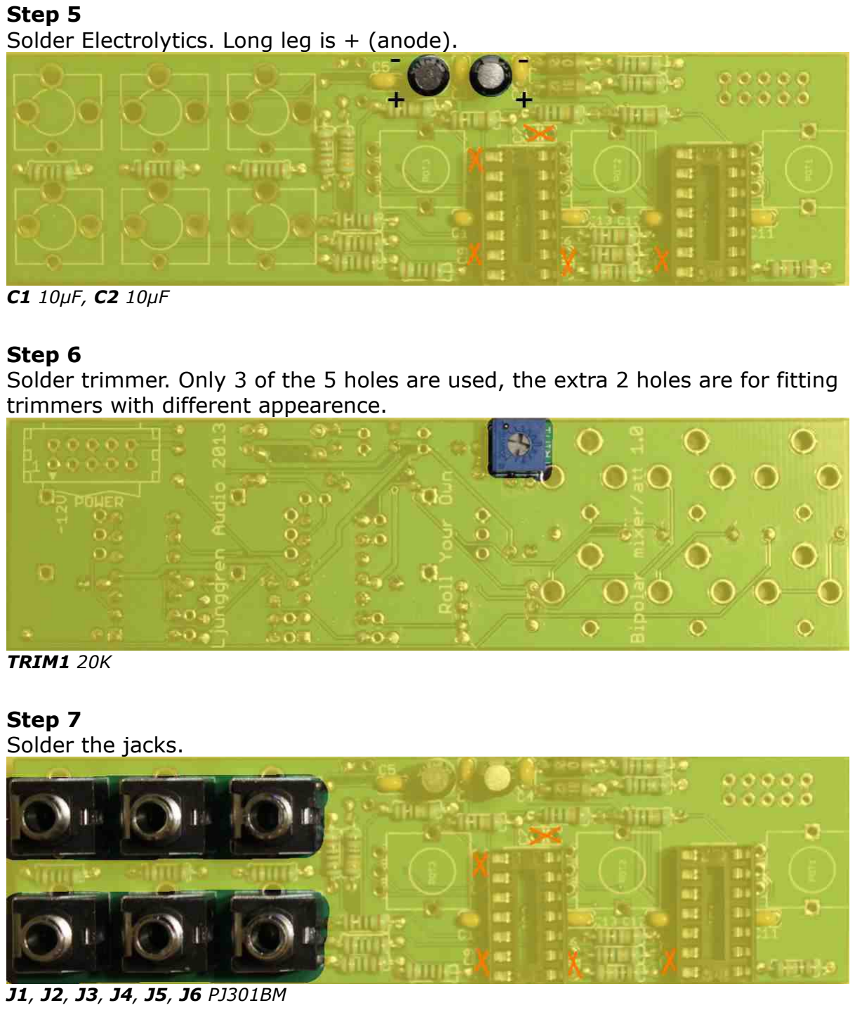
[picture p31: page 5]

Step 5
Solder Electrolytics. Long leg is + (anode).

C1 10µF, C2 10µF

Step 6
Solder trimmer. Only 3 of the 5 holes are used, the extra 2 holes are for fitting trimmers with different appearence.

TRIM1 20K

Step 7
Solder the jacks.

J1, J2, J3, J4, J5, J6 PJ301BM

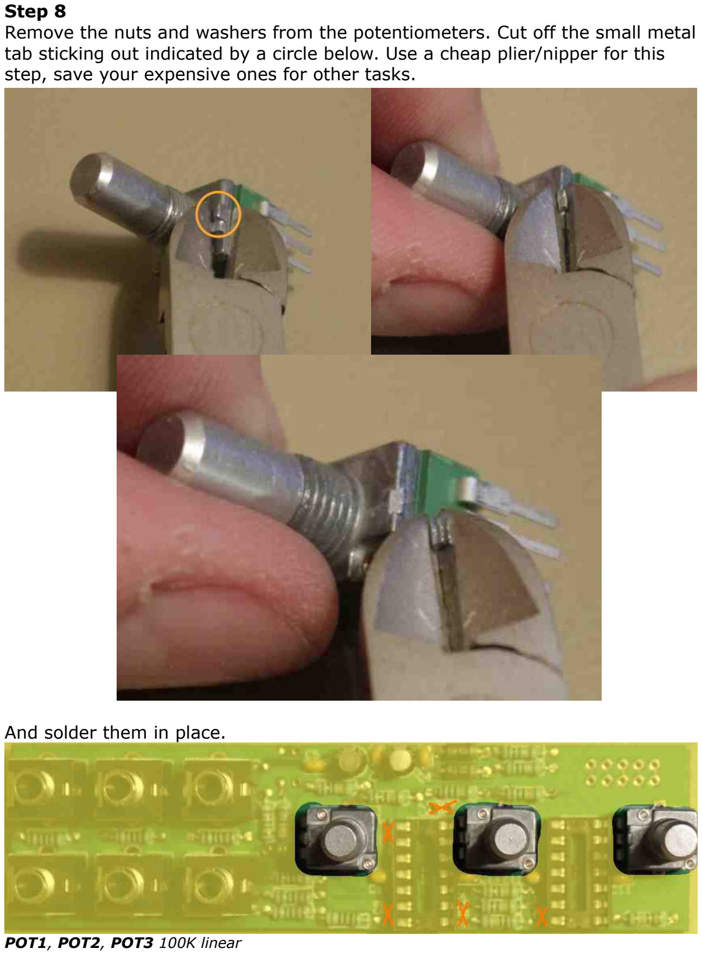
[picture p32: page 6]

Step 8
Remove the nuts and washers from the potentiometers. Cut off the small metal tab sticking out indicated by a circle below. Use a cheap plier/nipper for this step, save your expensive ones for other tasks.

And solder them in place.

POT1, POT2, POT3 100K linear

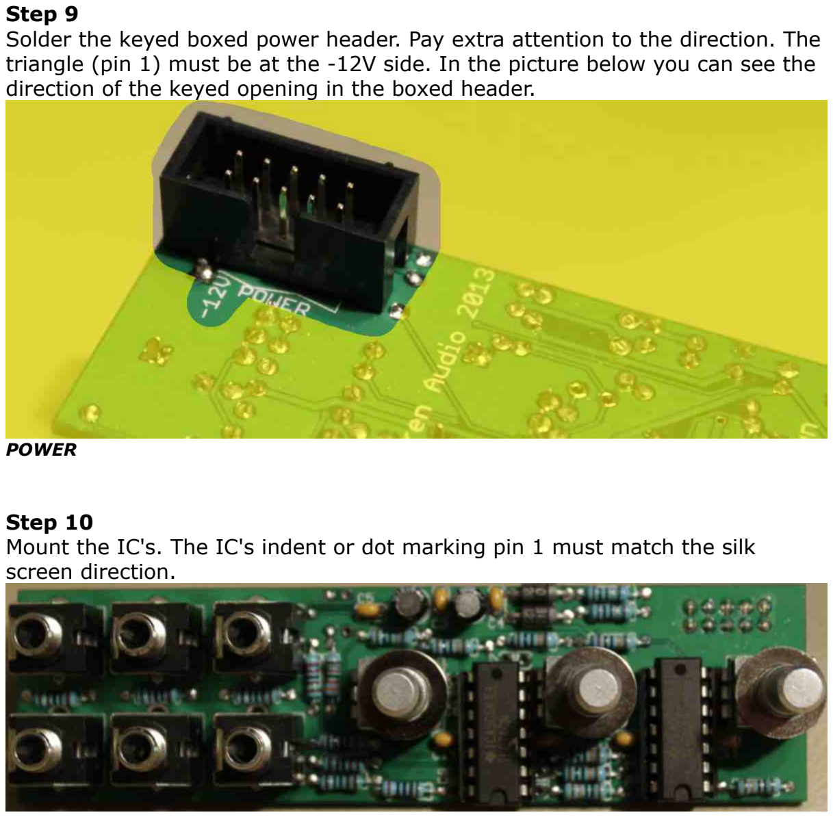
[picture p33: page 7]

Step 9
Solder the keyed boxed power header. Pay extra attention to the direction. The triangle (pin 1) must be at the -12V side. In the picture below you can see the direction of the keyed opening in the boxed header.

POWER

Step 10
Mount the IC's. The IC's indent or dot marking pin 1 must match the silk screen direction.

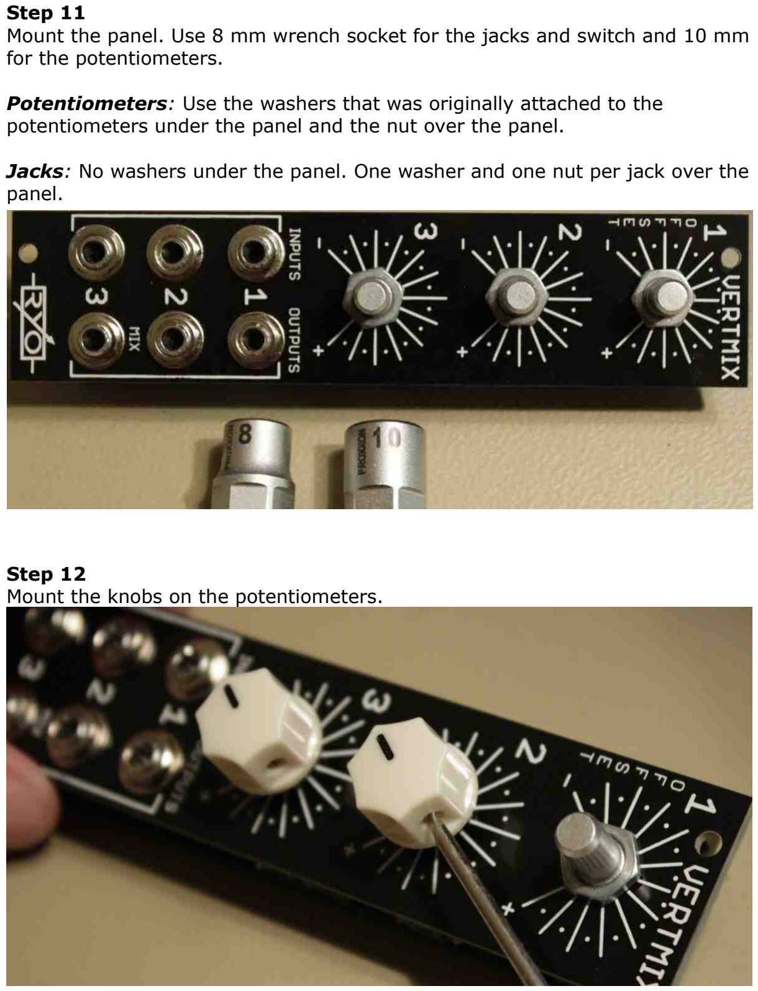
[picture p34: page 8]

Step 11
Mount the panel. Use 8 mm wrench socket for the jacks and switch and 10 mm for the potentiometers.

Potentiometers: Use the washers that was originally attached to the potentiometers under the panel and the nut over the panel.

Jacks: No washers under the panel. One washer and one nut per jack over the panel.

Step 12
Mount the knobs on the potentiometers.

Step 13
Mount the power cable. Red stripe at -12V.

Finished module!

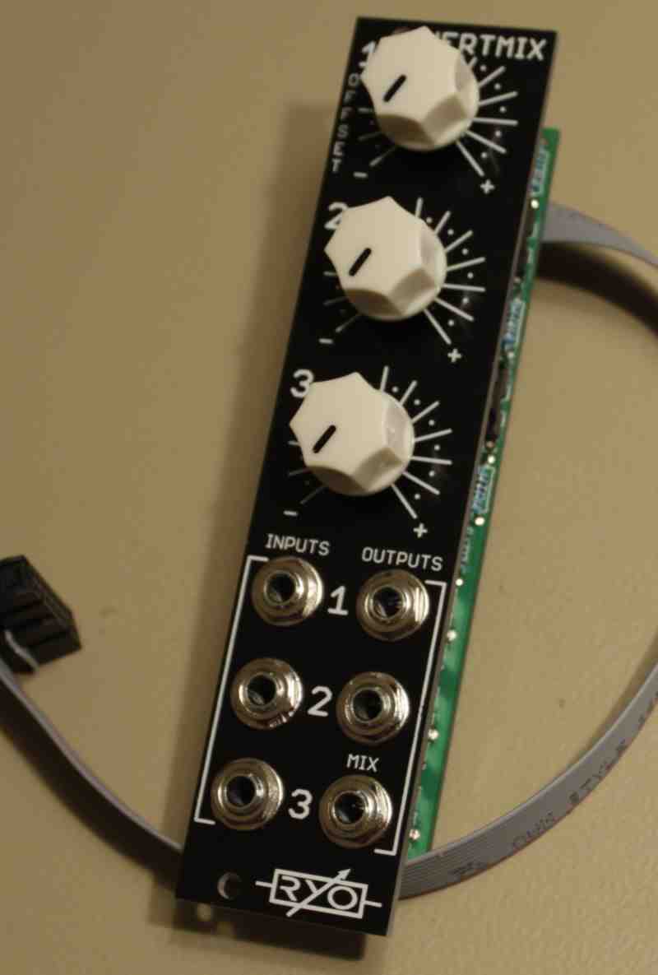
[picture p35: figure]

## Calibration

1.
Turn channel 1 knob fully CW (right).

2.
Connect a patch cable to channel 1 output. Leave channel 1 input jack unconnected.

3.
Measure voltage with a multimeter between the tip and ring (signal and ground) of the patch cable.

4.
Adjust trimmer until you measure 5V on the multimeter.

There will be some small variations between channel 1 out and mix out as well as between fully negative and fully positive setting, due to the use of 1% resistors and standard opamps with up to 6mV offset. If you use 0.1% resistors where the BOM say 1% and opamps with lower offset you will get better precision for offset, attenuating and mixing.

Although Vertmix have 1k isolation resistors on the outputs so if you patch them to inputs without resistorless buffers there will be a voltage droop and it will increase with passive multing.

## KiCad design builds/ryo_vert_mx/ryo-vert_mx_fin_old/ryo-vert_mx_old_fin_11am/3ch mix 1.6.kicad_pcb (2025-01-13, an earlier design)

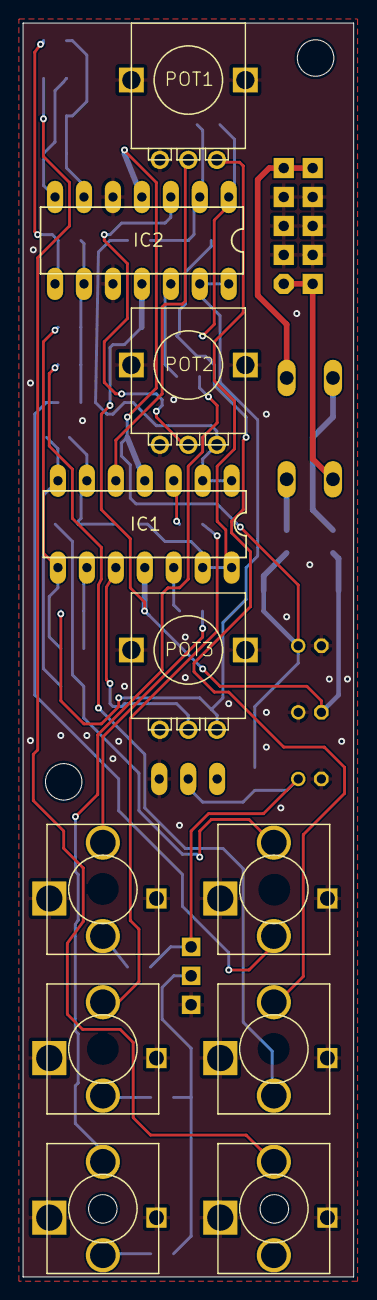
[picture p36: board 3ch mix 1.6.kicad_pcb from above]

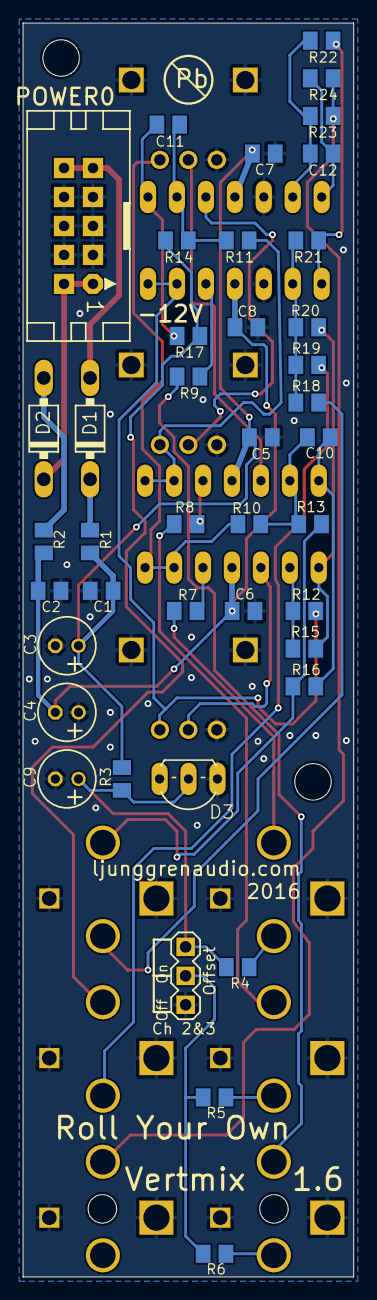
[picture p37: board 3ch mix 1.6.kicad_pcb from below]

Board: 2 copper layers, 29.0 x 110.0 mm, 56 parts (41 on the bottom side), 39 nets.

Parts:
@HOLE0, @HOLE1, @HOLE2, @HOLE3: (no value)
C1, C2, C5, C6, C7, C8: 100nF; C0805K
C3, C4, C9: 10uF; E2-5
C10, C11, C12: 68pF; C0805K
D1, D2: 1N5818; DO41-7
D3: LM4040 5V; TO92-LINE
IC1, IC2: TL084; DIL14
IN1, IN2, IN3: ERTHENVAR_3.5MM_JACKHOLES; ERTHENVAR
JP1: MA03-1
OUT1, OUT2, OUT3: ERTHENVAR_3.5MM_JACKHOLES; ERTHENVAR
POT1, POT2, POT3: 22K; POT-ALPHA9
POWER0: CON10L
R1, R2: 10R; C0805K
R3: 10K; C0805K
R4, R5, R6, R7, R8, R9, R10, R11, R12, R13, R14, R15, R18, R19, R20, R21, R22, R23: 22K; C0805K
R16, R17, R24: 330R; C0805K

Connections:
0V: C1.2, C2.1, C3.-, C4.+, C5.2, C6.1, C7.2, C8.1, C9.-, D3.3, IC2.5, IC2.10, IN1.RING1, IN1.RING2, IN2.RING1, IN2.RING2, IN3.RING1, IN3.RING2, JP1.1, OUT1.RING1, OUT1.RING2, OUT2.RING1, OUT2.RING2, OUT3.RING1, OUT3.RING2, POT1.GND$1, POT1.GND$2, POT1.LEFT, POT2.GND$1, POT2.GND$2, POT2.LEFT, POT3.GND$1, POT3.GND$2, POT3.LEFT, POWER0.3, POWER0.4, POWER0.5, POWER0.6, POWER0.7, POWER0.8
+12V: C1.1, C3.+, C5.1, C7.1, IC1.4, IC2.4, R1.2, R3.2
-12V: C2.2, C4.-, C6.2, C8.2, IC1.11, IC2.11, R2.2
unnamed: D1.A, POWER0.9, POWER0.10
unnamed: D2.C, POWER0.1, POWER0.2
unnamed: IC2.8, R21.2, R22.1
unnamed: C12.1, IC2.6, R22.2, R23.1
unnamed: D1.C, R1.1
unnamed: D2.A, R2.1
unnamed: C9.+, D3.2, JP1.3, R3.1, R4.1
unnamed: OUT1.TIP, R13.2, R16.2
unnamed: IC1.12, R7.2
unnamed: IC1.3, R8.2
unnamed: IC2.12, R9.2
unnamed: IC1.13, IC1.14, POT1.RIGHT, R10.1
unnamed: IC1.1, IC1.2, POT2.RIGHT, R11.1
unnamed: IC2.13, IC2.14, POT3.RIGHT, R12.1
unnamed: C10.2, IC1.6, R10.2, R13.1
unnamed: IC1.5, POT1.MID
unnamed: IC2.3, POT2.MID
unnamed: IC1.10, POT3.MID
unnamed: OUT2.TIP, R14.2, R17.2
unnamed: IN1.TIP, R7.1
unnamed: C11.2, IC2.2, R11.2, R14.1
unnamed: IC1.9, R12.2, R15.1
unnamed: OUT3.TIP, R23.2, R24.2
unnamed: IN2.TIP, R8.1
unnamed: IC1.8, R15.2, R20.1
unnamed: OUT1.SHUNT, R18.1
unnamed: OUT2.SHUNT, R19.1
unnamed: IC2.9, R18.2, R19.2, R20.2, R21.1
unnamed: C12.2, IC2.7, R24.1
unnamed: IN1.SHUNT, R4.2
unnamed: IN2.SHUNT, R5.2
unnamed: IN3.SHUNT, R6.2
unnamed: JP1.2, R5.1, R6.1
unnamed: IN3.TIP, R9.1
unnamed: C10.1, IC1.7, R16.1
unnamed: C11.1, IC2.1, R17.1

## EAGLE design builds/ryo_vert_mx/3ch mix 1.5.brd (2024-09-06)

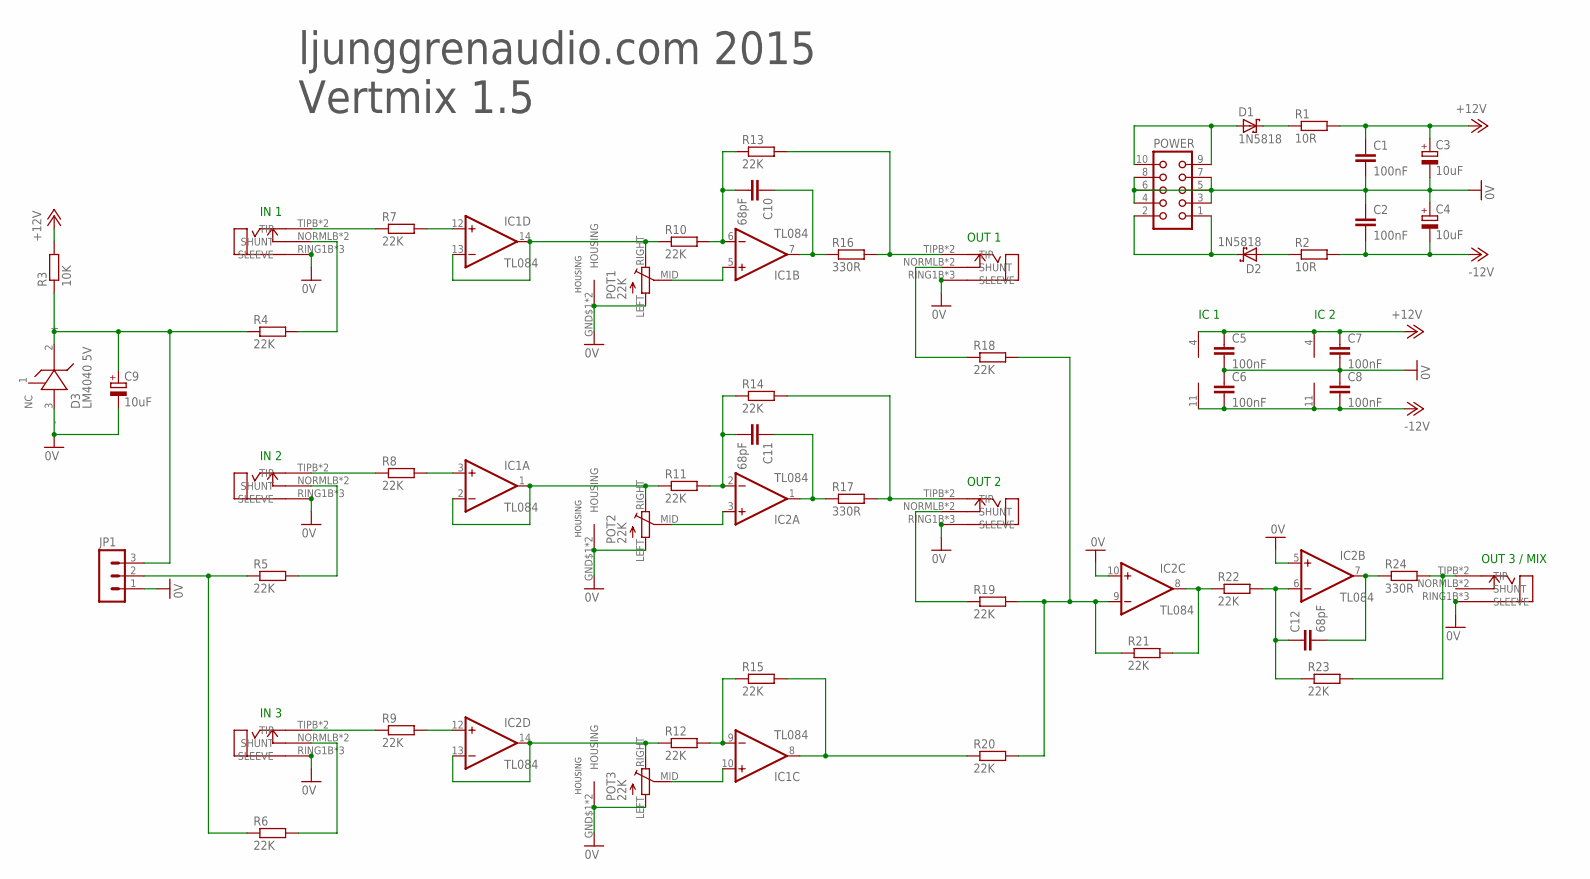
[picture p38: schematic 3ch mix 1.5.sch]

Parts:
C1, C2, C5, C6, C7, C8: 100nF; C0805K
C3, C4, C9: 10uF; E2-5
C10, C11, C12: 68pF; C0805K
D1, D2: 1N5818; DO41-7
D3: LM4040 5V; TO92-LINE
IC1, IC2: TL084; DIL14
IN1, IN2, IN3: ERTHENVAR_3.5MM_JACKSLOTS; ERTHENVAR-SLOTS
JP1: MA03-1
OUT1, OUT2, OUT3: ERTHENVAR_3.5MM_JACKSLOTS; ERTHENVAR-SLOTS
POT1, POT2, POT3: 22K; POT-ALPHA9
POWER: CON10L
R1, R2: 10R; C0805K
R3: 10K; C0805K
R4, R5, R6, R7, R8, R9, R10, R11, R12, R13, R14, R15, R18, R19, R20, R21, R22, R23: 22K; C0805K
R16, R17, R24: 330R; C0805K

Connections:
0V: C1.2, C2.1, C3.-, C4.+, C5.2, C6.1, C7.2, C8.1, C9.-, D3.3 (-), IC2.5 (+IN), IC2.10 (+IN), IN1.RING1B (SLEEVE), IN1.RING1T (SLEEVE), IN1.RING2H (SLEEVE), IN2.RING1B (SLEEVE), IN2.RING1T (SLEEVE), IN2.RING2H (SLEEVE), IN3.RING1B (SLEEVE), IN3.RING1T (SLEEVE), IN3.RING2H (SLEEVE), JP1.1, OUT1.RING1B (SLEEVE), OUT1.RING1T (SLEEVE), OUT1.RING2H (SLEEVE), OUT2.RING1B (SLEEVE), OUT2.RING1T (SLEEVE), OUT2.RING2H (SLEEVE), OUT3.RING1B (SLEEVE), OUT3.RING1T (SLEEVE), OUT3.RING2H (SLEEVE), POT1.GND$1 (HOUSING), POT1.GND$2 (HOUSING), POT1.LEFT, POT2.GND$1 (HOUSING), POT2.GND$2 (HOUSING), POT2.LEFT, POT3.GND$1 (HOUSING), POT3.GND$2 (HOUSING), POT3.LEFT, POWER.3, POWER.4, POWER.5, POWER.6, POWER.7, POWER.8
+12V: C1.1, C3.+, C5.1, C7.1, IC1.4 (V+), IC2.4 (V+), R1.2, R3.2
-12V: C2.2, C4.-, C6.2, C8.2, IC1.11 (V-), IC2.11 (V-), R2.2
unnamed: D1.A, POWER.9, POWER.10
unnamed: D2.C, POWER.1, POWER.2
unnamed: IC2.8 (OUT), R21.2, R22.1
unnamed: C12.1, IC2.6 (-IN), R22.2, R23.1
unnamed: D1.C, R1.1
unnamed: D2.A, R2.1
unnamed: C9.+, D3.2 (+), JP1.3, R3.1, R4.1
unnamed: OUT1.TIPB (TIP), OUT1.TIPT (TIP), R13.2, R16.2
unnamed: IC1.12 (+IN), R7.2
unnamed: IC1.3 (+IN), R8.2
unnamed: IC2.12 (+IN), R9.2
unnamed: IC1.13 (-IN), IC1.14 (OUT), POT1.RIGHT, R10.1
unnamed: IC1.1 (OUT), IC1.2 (-IN), POT2.RIGHT, R11.1
unnamed: IC2.13 (-IN), IC2.14 (OUT), POT3.RIGHT, R12.1
unnamed: C10.2, IC1.6 (-IN), R10.2, R13.1
unnamed: IC1.5 (+IN), POT1.MID
unnamed: IC2.3 (+IN), POT2.MID
unnamed: IC1.10 (+IN), POT3.MID
unnamed: OUT2.TIPB (TIP), OUT2.TIPT (TIP), R14.2, R17.2
unnamed: IN1.TIPB (TIP), IN1.TIPT (TIP), R7.1
unnamed: C11.2, IC2.2 (-IN), R11.2, R14.1
unnamed: IC1.9 (-IN), R12.2, R15.1
unnamed: OUT3.TIPB (TIP), OUT3.TIPT (TIP), R23.2, R24.2
unnamed: IN2.TIPB (TIP), IN2.TIPT (TIP), R8.1
unnamed: IC1.8 (OUT), R15.2, R20.1
unnamed: OUT1.NORMLB (SHUNT), OUT1.NORMLT (SHUNT), R18.1
unnamed: OUT2.NORMLB (SHUNT), OUT2.NORMLT (SHUNT), R19.1
unnamed: IC2.9 (-IN), R18.2, R19.2, R20.2, R21.1
unnamed: C12.2, IC2.7 (OUT), R24.1
unnamed: IN1.NORMLB (SHUNT), IN1.NORMLT (SHUNT), R4.2
unnamed: IN2.NORMLB (SHUNT), IN2.NORMLT (SHUNT), R5.2
unnamed: IN3.NORMLB (SHUNT), IN3.NORMLT (SHUNT), R6.2
unnamed: JP1.2, R5.1, R6.1
unnamed: IN3.TIPB (TIP), IN3.TIPT (TIP), R9.1
unnamed: C10.1, IC1.7 (OUT), R16.1
unnamed: C11.1, IC2.1 (OUT), R17.1

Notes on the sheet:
IN 1
IN 2
IN 3
OUT 1
OUT 2
OUT 3 / MIX
IC 1
IC 2
HOUSING
ljunggrenaudio.com 2015 Vertmix 1.5

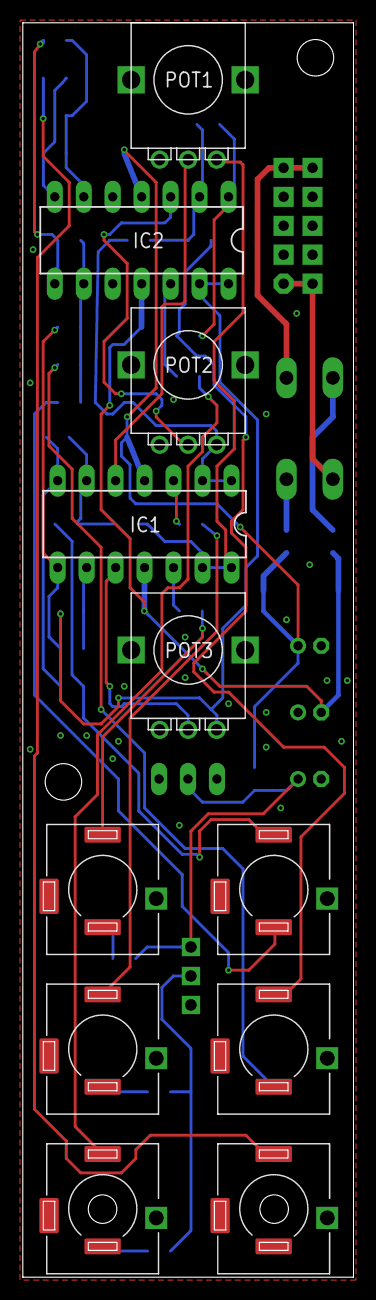
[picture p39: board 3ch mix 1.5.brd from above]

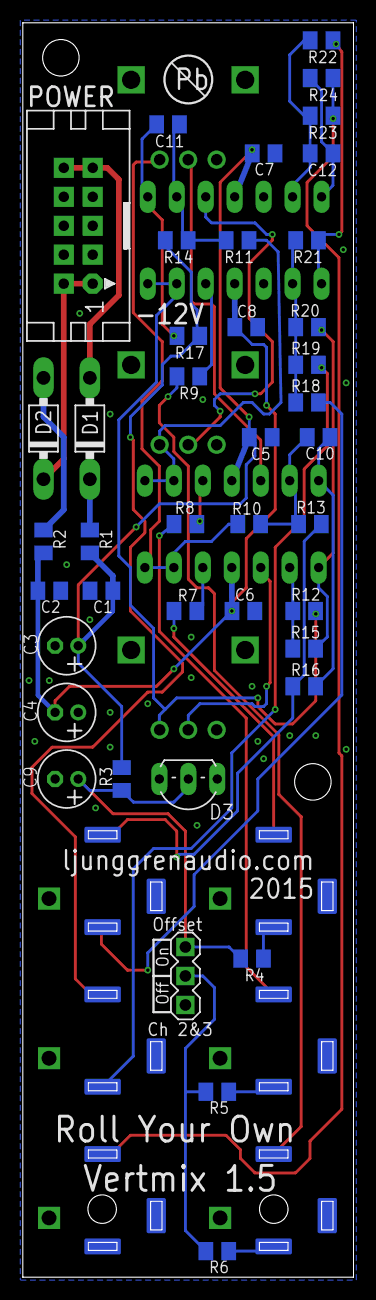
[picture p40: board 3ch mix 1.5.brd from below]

Board: 2 copper layers, 29.0 x 110.0 mm, 52 parts (41 on the bottom side), 39 nets.

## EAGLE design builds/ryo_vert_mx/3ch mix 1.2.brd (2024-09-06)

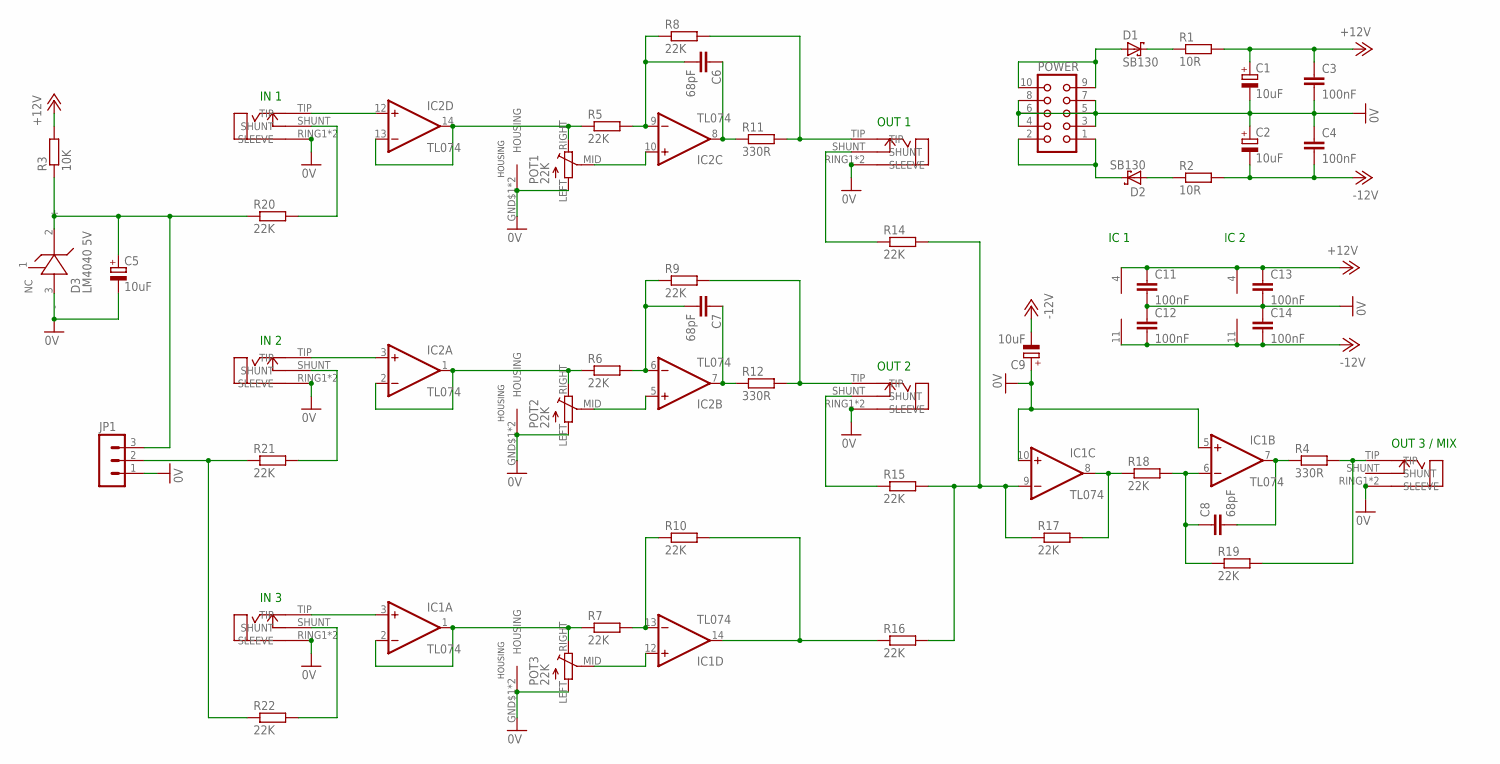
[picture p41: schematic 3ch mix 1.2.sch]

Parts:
C1, C2, C5, C9: 10uF; E2-5
C3, C4, C11, C12, C13, C14: 100nF; C025-024X044
C6, C7, C8: 68pF; C025-024X044
D1, D2: SB130; DO41-7
D3: LM4040 5V; TO92-LINE
IC1, IC2: TL074; DIL14
IN1, IN2, IN3: ERTHENVAR_3.5MM_JACK; ERTHENVAR
JP1: MA03-1
OUT1, OUT2, OUT3: ERTHENVAR_3.5MM_JACK; ERTHENVAR
POT1, POT2, POT3: 22K; POT-ALPHA9
POWER: CON10L
R1, R2: 10R; 0207/9
R3: 10K; 0204/5
R4, R11, R12: 330R; 0204/5
R5, R6, R7, R8, R9, R10, R14, R15, R16, R17, R18, R19, R20, R21, R22: 22K; 0204/5

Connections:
0V: C1.-, C2.+, C3.2, C4.1, C5.-, C9.+, C11.2, C12.1, C13.2, C14.1, D3.3 (-), IC1.5 (+IN), IC1.10 (+IN), IN1.RING1 (SLEEVE), IN1.RING2 (SLEEVE), IN2.RING1 (SLEEVE), IN2.RING2 (SLEEVE), IN3.RING1 (SLEEVE), IN3.RING2 (SLEEVE), JP1.1, OUT1.RING1 (SLEEVE), OUT1.RING2 (SLEEVE), OUT2.RING1 (SLEEVE), OUT2.RING2 (SLEEVE), OUT3.RING1 (SLEEVE), OUT3.RING2 (SLEEVE), POT1.GND$1 (HOUSING), POT1.GND$2 (HOUSING), POT1.LEFT, POT2.GND$1 (HOUSING), POT2.GND$2 (HOUSING), POT2.LEFT, POT3.GND$1 (HOUSING), POT3.GND$2 (HOUSING), POT3.LEFT, POWER.3, POWER.4, POWER.5, POWER.6, POWER.7, POWER.8
+12V: C1.+, C3.1, C11.1, C13.1, IC1.4 (V+), IC2.4 (V+), R1.2, R3.2
-12V: C2.-, C4.2, C9.-, C12.2, C14.2, IC1.11 (V-), IC2.11 (V-), R2.2
unnamed: D1.A, POWER.9, POWER.10
unnamed: D2.C, POWER.1, POWER.2
unnamed: IC1.8 (OUT), R17.2, R18.1
unnamed: C8.1, IC1.6 (-IN), R18.2, R19.1
unnamed: D1.C, R1.1
unnamed: D2.A, R2.1
unnamed: C5.+, D3.2 (+), JP1.3, R3.1, R20.1
unnamed: C6.1, IC2.8 (OUT), R11.1
unnamed: IC2.12 (+IN), IN1.TIP
unnamed: IC2.3 (+IN), IN2.TIP
unnamed: IC1.3 (+IN), IN3.TIP
unnamed: IC2.13 (-IN), IC2.14 (OUT), POT1.RIGHT, R5.1
unnamed: IC2.1 (OUT), IC2.2 (-IN), POT2.RIGHT, R6.1
unnamed: IC1.1 (OUT), IC1.2 (-IN), POT3.RIGHT, R7.1
unnamed: C6.2, IC2.9 (-IN), R5.2, R8.1
unnamed: IC2.10 (+IN), POT1.MID
unnamed: IC2.5 (+IN), POT2.MID
unnamed: IC1.12 (+IN), POT3.MID
unnamed: OUT1.TIP, R8.2, R11.2
unnamed: OUT2.TIP, R9.2, R12.2
unnamed: C7.2, IC2.6 (-IN), R6.2, R9.1
unnamed: IC1.13 (-IN), R7.2, R10.1
unnamed: OUT3.TIP, R4.2, R19.2
unnamed: C7.1, IC2.7 (OUT), R12.1
unnamed: IC1.14 (OUT), R10.2, R16.1
unnamed: OUT1.SHUNT, R14.1
unnamed: OUT2.SHUNT, R15.1
unnamed: IC1.9 (-IN), R14.2, R15.2, R16.2, R17.1
unnamed: C8.2, IC1.7 (OUT), R4.1
unnamed: IN1.SHUNT, R20.2
unnamed: IN2.SHUNT, R21.2
unnamed: IN3.SHUNT, R22.2
unnamed: JP1.2, R21.1, R22.1

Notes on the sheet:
IN 1
IN 2
IN 3
OUT 1
OUT 2
OUT 3 / MIX
IC 1
IC 2
HOUSING

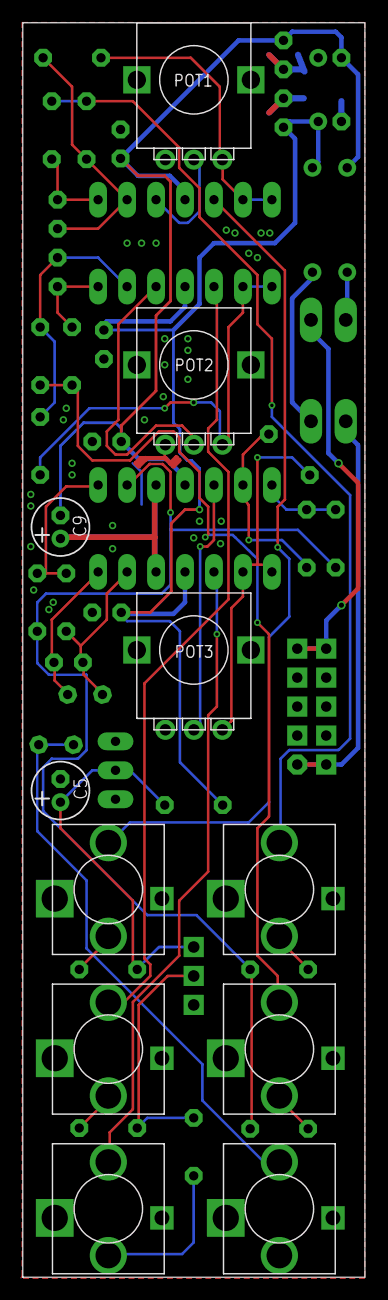
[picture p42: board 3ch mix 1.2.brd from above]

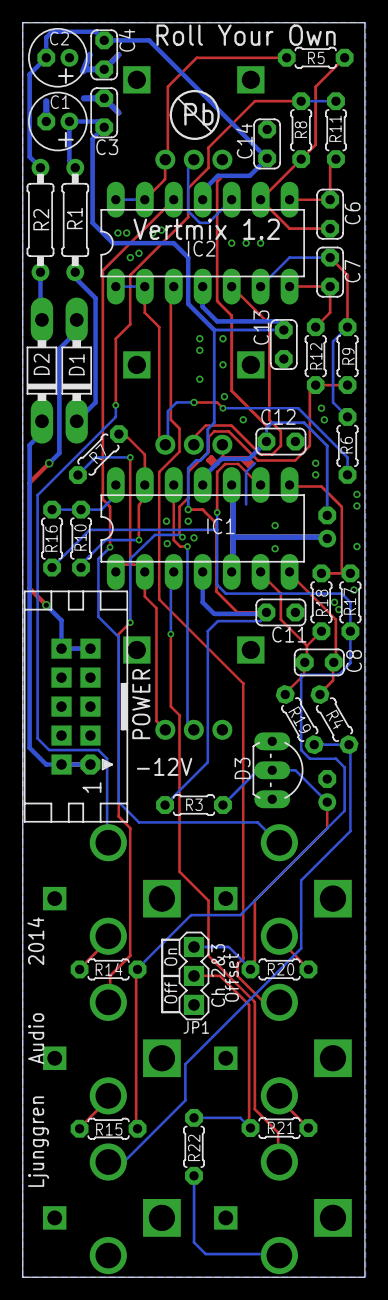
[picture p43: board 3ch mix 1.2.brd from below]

Board: 2 copper layers, 30.0 x 110.0 mm, 50 parts (39 on the bottom side), 36 nets.

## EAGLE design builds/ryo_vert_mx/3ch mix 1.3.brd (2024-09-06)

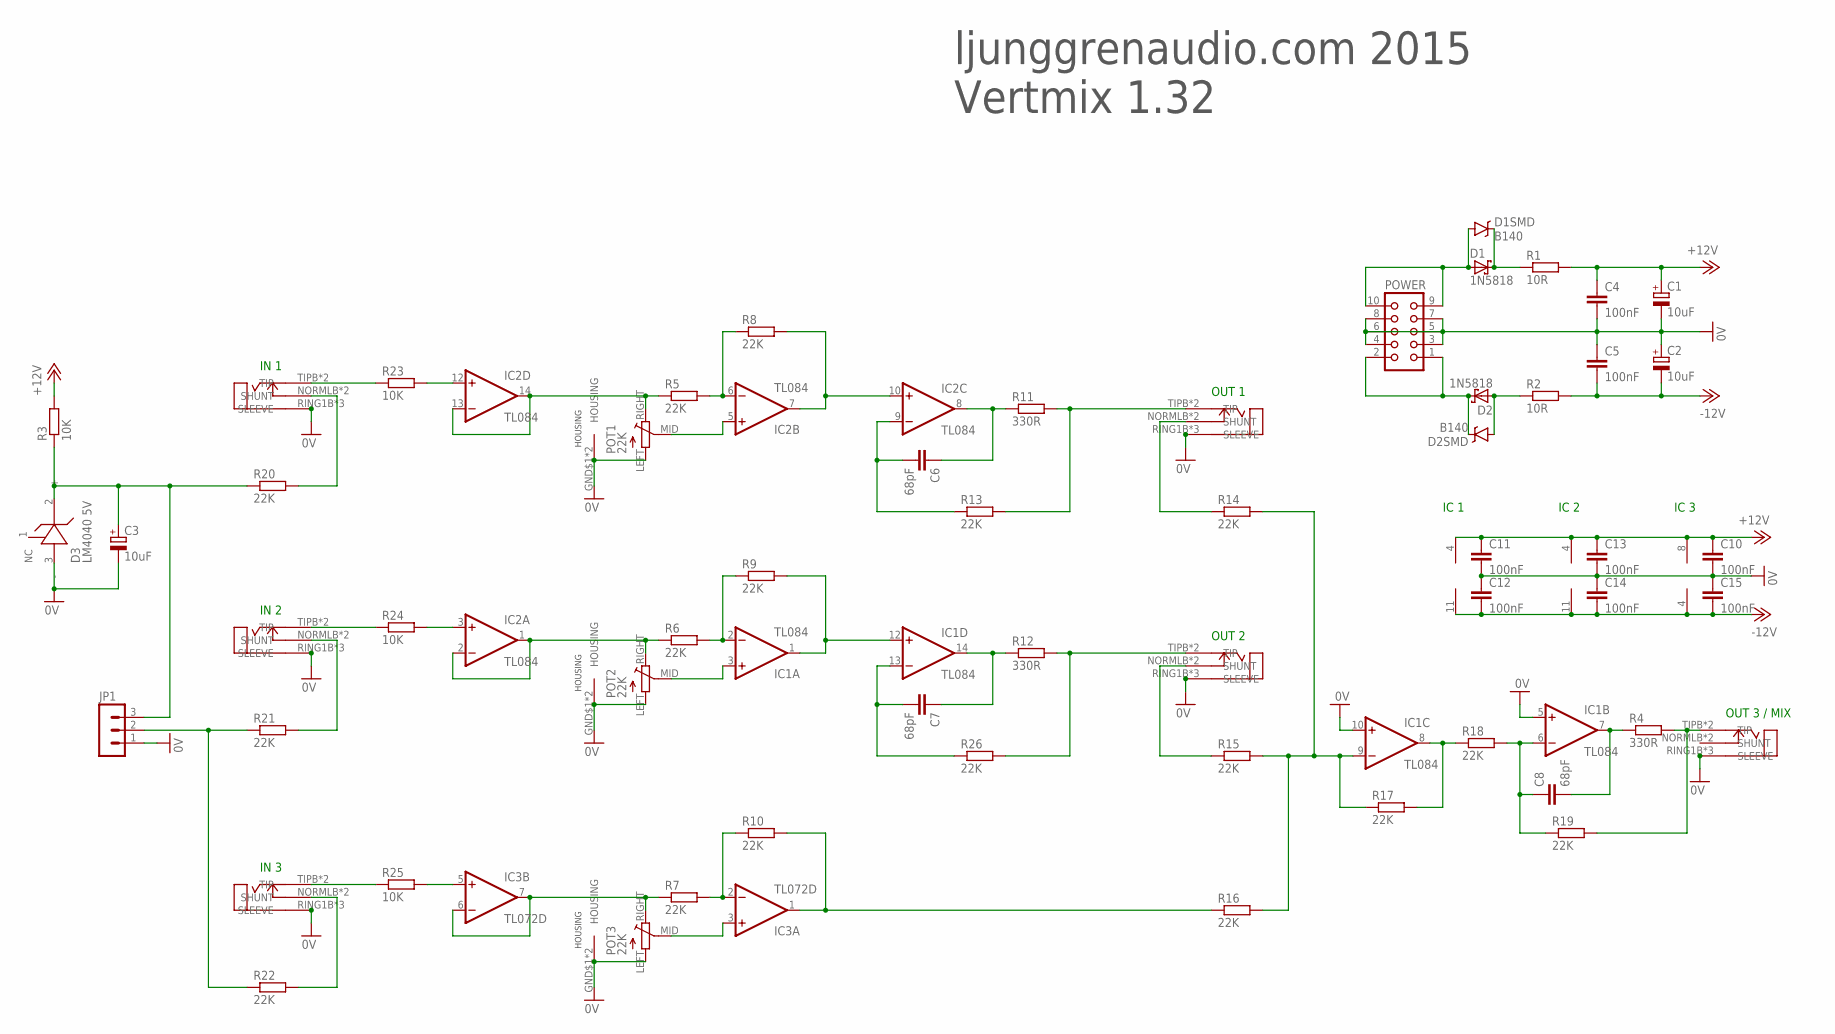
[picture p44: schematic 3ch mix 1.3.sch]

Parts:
C1, C2, C3: 10uF; E2-5
C4, C5, C10, C11, C12, C13, C14, C15: 100nF; C0805K
C6, C7, C8: 68pF; C0805K
D1, D2: 1N5818; DO41-7
D1SMD, D2SMD: B140; SMA-DIODE
D3: LM4040 5V; TO92-LINE
IC1, IC2: TL084; SO14
IC3: TL072D; SO08
IN1, IN2, IN3: ERTHENVAR_3.5MM_JACKSLOTS; ERTHENVAR-SLOTS
JP1: MA03-1
OUT1, OUT2, OUT3: ERTHENVAR_3.5MM_JACKSLOTS; ERTHENVAR-SLOTS
POT1, POT2, POT3: 22K; POT-ALPHA9
POWER: CON10L
R1, R2: 10R; C0805K
R3, R23, R24, R25: 10K; C0805K
R4, R11, R12: 330R; C0805K
R5, R6, R7, R8, R9, R10, R13, R14, R15, R16, R17, R18, R19, R20, R21, R22, R26: 22K; C0805K

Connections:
0V: C1.-, C2.+, C3.-, C4.2, C5.1, C10.2, C11.2, C12.1, C13.2, C14.1, C15.1, D3.3 (-), IC1.5 (+IN), IC1.10 (+IN), IN1.RING1B (SLEEVE), IN1.RING1T (SLEEVE), IN1.RING2H (SLEEVE), IN2.RING1B (SLEEVE), IN2.RING1T (SLEEVE), IN2.RING2H (SLEEVE), IN3.RING1B (SLEEVE), IN3.RING1T (SLEEVE), IN3.RING2H (SLEEVE), JP1.1, OUT1.RING1B (SLEEVE), OUT1.RING1T (SLEEVE), OUT1.RING2H (SLEEVE), OUT2.RING1B (SLEEVE), OUT2.RING1T (SLEEVE), OUT2.RING2H (SLEEVE), OUT3.RING1B (SLEEVE), OUT3.RING1T (SLEEVE), OUT3.RING2H (SLEEVE), POT1.GND$1 (HOUSING), POT1.GND$2 (HOUSING), POT1.LEFT, POT2.GND$1 (HOUSING), POT2.GND$2 (HOUSING), POT2.LEFT, POT3.GND$1 (HOUSING), POT3.GND$2 (HOUSING), POT3.LEFT, POWER.3, POWER.4, POWER.5, POWER.6, POWER.7, POWER.8
+12V: C1.+, C4.1, C10.1, C11.1, C13.1, IC1.4 (V+), IC2.4 (V+), IC3.8 (V+), R1.2, R3.2
-12V: C2.-, C5.2, C12.2, C14.2, C15.2, IC1.11 (V-), IC2.11 (V-), IC3.4 (V-), R2.2
unnamed: D1.A, D1SMD.A, POWER.9, POWER.10
unnamed: D2.C, D2SMD.C, POWER.1, POWER.2
unnamed: IC1.8 (OUT), R17.2, R18.1
unnamed: C8.1, IC1.6 (-IN), R18.2, R19.1
unnamed: D1.C, D1SMD.C, R1.1
unnamed: D2.A, D2SMD.A, R2.1
unnamed: C3.+, D3.2 (+), JP1.3, R3.1, R20.1
unnamed: IC2.7 (OUT), IC2.10 (+IN), R8.2
unnamed: IC2.12 (+IN), R23.2
unnamed: IC2.3 (+IN), R24.2
unnamed: IC3.5 (+IN), R25.2
unnamed: IC2.13 (-IN), IC2.14 (OUT), POT1.RIGHT, R5.1
unnamed: IC2.1 (OUT), IC2.2 (-IN), POT2.RIGHT, R6.1
unnamed: IC3.6 (-IN), IC3.7 (OUT), POT3.RIGHT, R7.1
unnamed: IC2.6 (-IN), R5.2, R8.1
unnamed: IC2.5 (+IN), POT1.MID
unnamed: IC1.3 (+IN), POT2.MID
unnamed: IC3.3 (+IN), POT3.MID
unnamed: IC1.1 (OUT), IC1.12 (+IN), R9.2
unnamed: IN1.TIPB (TIP), IN1.TIPT (TIP), R23.1
unnamed: IC1.2 (-IN), R6.2, R9.1
unnamed: IC3.2 (-IN), R7.2, R10.1
unnamed: OUT3.TIPB (TIP), OUT3.TIPT (TIP), R4.2, R19.2
unnamed: IN2.TIPB (TIP), IN2.TIPT (TIP), R24.1
unnamed: IC3.1 (OUT), R10.2, R16.1
unnamed: OUT1.NORMLB (SHUNT), OUT1.NORMLT (SHUNT), R14.1
unnamed: OUT2.NORMLB (SHUNT), OUT2.NORMLT (SHUNT), R15.1
unnamed: IC1.9 (-IN), R14.2, R15.2, R16.2, R17.1
unnamed: C8.2, IC1.7 (OUT), R4.1
unnamed: IN1.NORMLB (SHUNT), IN1.NORMLT (SHUNT), R20.2
unnamed: IN2.NORMLB (SHUNT), IN2.NORMLT (SHUNT), R21.2
unnamed: IN3.NORMLB (SHUNT), IN3.NORMLT (SHUNT), R22.2
unnamed: JP1.2, R21.1, R22.1
unnamed: IN3.TIPB (TIP), IN3.TIPT (TIP), R25.1
unnamed: C6.2, IC2.9 (-IN), R13.1
unnamed: OUT1.TIPB (TIP), OUT1.TIPT (TIP), R11.2, R13.2
unnamed: C6.1, IC2.8 (OUT), R11.1
unnamed: C7.1, IC1.14 (OUT), R12.1
unnamed: OUT2.TIPB (TIP), OUT2.TIPT (TIP), R12.2, R26.2
unnamed: C7.2, IC1.13 (-IN), R26.1

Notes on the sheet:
IN 1
IN 2
IN 3
OUT 1
OUT 2
OUT 3 / MIX
IC 1
IC 2
HOUSING
IC 3
ljunggrenaudio.com 2015 Vertmix 1.32

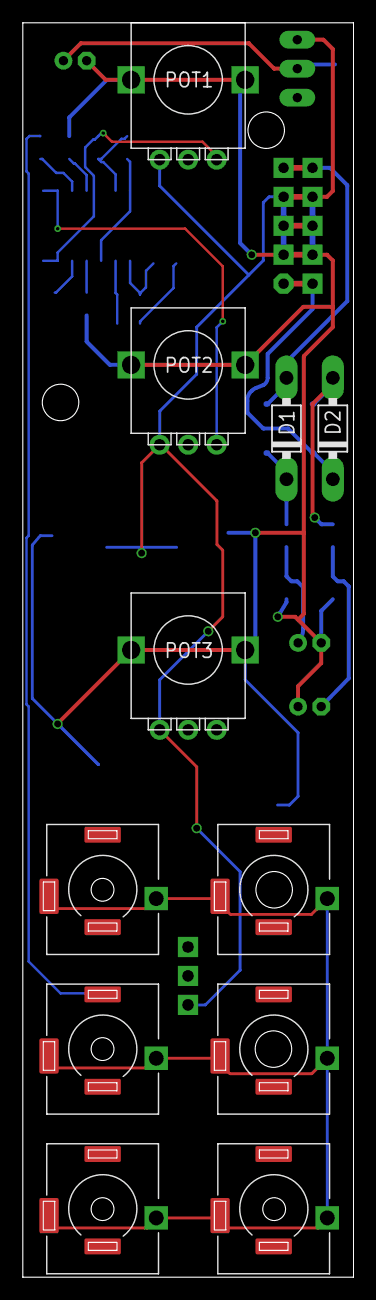
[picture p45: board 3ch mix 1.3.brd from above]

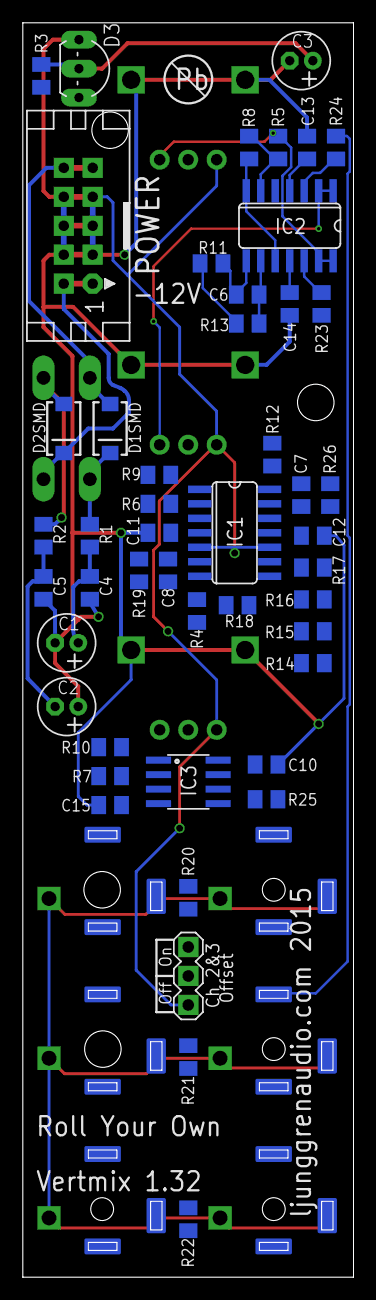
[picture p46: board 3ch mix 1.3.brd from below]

Board: 2 copper layers, 29.0 x 110.0 mm, 59 parts (48 on the bottom side), 43 nets.

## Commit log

2024-08-30 init commit or ryomldular.com vert_mx
    as usual the init commit is a mess of random unsorted carnage that eventually gets cleaned and tidied and generally sorted into a pro[er project poeple can make sense of...
    [3ch mix 1.6_board_outline.gm1, 3ch mix 1.6_bottom_copper.gbl, 3ch mix 1.6_bottom_silk.gbo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]
2024-09-06 added a coupla files i guess
    [3ch mix 1.2.brd, 3ch mix 1.2.sch, 3ch mix 1.3 version 2.brd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]
2024-09-29 create vert_mx gerbers.zip
    shop asked for repeats /shrug
2024-10-02 tidying up mess from init commit
    just filing things away into neat lil folders
    [3ch mix 1.2.brd, 3ch mix 1.2.sch, 3ch mix 1.3 version 2.brd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]
2025-01-07 new crap added npow it's released and fuinally off my radar
    good to see end of this - now i can tidy this gitinto a comprhensible state
    [3ch mix 1.6.sch, Vertmix 1.2 BOM.ods, homepage.ods]
2025-01-08 t i d y
    omg for realz
    [3ch mix 1.2.brd, 3ch mix 1.2.sch, 3ch mix 1.3 version 2.brd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]
2025-01-13 wow a lotta stuff
    dunno what
    [3ch mix 1.2.brd, 3ch mix 1.2.sch, 3ch mix 1.3 version 2.brd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]

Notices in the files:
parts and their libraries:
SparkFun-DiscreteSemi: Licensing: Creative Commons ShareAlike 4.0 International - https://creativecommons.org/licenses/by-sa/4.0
